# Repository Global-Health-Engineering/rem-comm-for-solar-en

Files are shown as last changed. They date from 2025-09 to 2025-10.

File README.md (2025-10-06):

<!-- badges: start -->


<!-- badges: end -->

<h1> Development of a Remote Communications Infrastructure for an Off-Grid Energy System: Hardware, Software, and Data </h1>

<b>Contributors</b>  
- Jerun Voeten <a href="https://orcid.org/0009-0009-9822-1285">
ORCID logo 0009-0009-9822-1285
</a> *author, developer, maintainer*  
- Rebecca Alcock <a href="https://orcid.org/0000-0002-6884-9583">
ORCID logo 0000-0002-6884-9583
</a> *supervisor*  
- Jakub Tkaczuk <a href="https://orcid.org/0000-0001-7997-9423">
ORCID logo 0000-0001-7997-9423
</a> *supervisor, maintainer*  
- Elizabeth Tilley <a href="https://orcid.org/0000-0002-2095-9724">
ORCID logo 0000-0002-2095-9724
</a> *supervisor*  

<br>
<p align="middle"> 

<br><br>
It complements the openly-accessible master’s thesis, available on the<br \>  
<a href="">ETH Research Collection</a>.
</p>

# Overview
Monitoring off-grid energy systems in remote locations with unreliable communications is challenging, yet it is essential in health facilities where continuous power supports patient care. Currently, there is no simple end-to-end solution that reliably captures all relevant variables and forwards them autonomously to a site with internet access for analysis and response.

This thesis develops such a system for an off-grid health clinic in Tezhumke, northern Colombia. The design combines existing low-power sensing and long-range radio techniques with practical extensions for constrained clinical sites. In particular, robustness measures and encoding optimizations were added to improve packet delivery over Long Range (LoRa) links, and the overall architecture was engineered to run autonomously from small photovoltaic panels and local power bank storage.

Custom sensor nodes record key measurements: medical refrigerator temperature and humidity, electrical parameters of the off-grid power system, and environmental data. Measurements are transmitted over LoRa and Long Range Wide-Area Network (LoRaWAN) to a gateway, visualized on an Internet of Things (IoT) platform (ThingsBoard), and automatically archived. Alarm rules notify remote researchers and on-site staff via platform alerts, email, SMS, and visual signals when thresholds are exceeded.

In a 7-day field trial, the system achieved a packet reception rate of 97.64% over a distance of 8.5km and demonstrated stable autonomous operation. These results confirm that the system is a mature prototype ready for extended field trials and potential deployment in real-world conditions. Future work should include extended seasonal testing, long-term studies of battery aging, and improvements to the weatherproofing of individual components.

Beyond the immediate use case in Tezhumke, the system may also be applicable to other similarly affected clinics or remote sites. With further refinement, it could support predictive maintenance strategies and contribute to improved reliability of off-grid power supplies, thereby strengthening healthcare delivery in underserved regions.

# Repository
As part of this Master thesis, all developed resources have been collected and systematically documented in this public GitHub repository. The repository serves as a comprehensive reference point for future research and practical applications. It includes:

- Source code for LoRa / LoRaWAN communication,
- ThingsBoard dashboard configuration and the main payload decryption script,
- Dedicated scripts for automated data export,
- PCB layouts and electronic circuit schematics,
- All custom-designed 3D models provided in STL format,
- A complete bill of materials for all hardware components.

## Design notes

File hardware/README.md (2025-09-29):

# `hardware`

This directory contains 3D designs, PCB layouts (KiCad), LoRa32u4II datasheet and a complete bill of materials for all hardware components.

# Power Bank Warning

Wires have been soldered to the + and – terminals of the power bank PCB (Solar Manager C). As a result, the manufacturer’s warranty is void, and I do not assume any responsibility in the event of issues, fire, or other incidents.
However, during the testing phase everything worked without any problems, and the functionality of the power bank did not appear to be affected.

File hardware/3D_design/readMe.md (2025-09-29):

# `hardware/3D_design`

This directory contains 3D designs for parts used in the project.

# Prior work

The Stevenson screen used in this work was adapted from the version originally created by [PYXIS. (2025, September 16). Stevenson Screen (Universal sensor mount) [STL file]. Bambu Studio](https://makerworld.com/de/models/851650-stevenson-screen-universal-sensor-mount?from=search#profileId-799909).

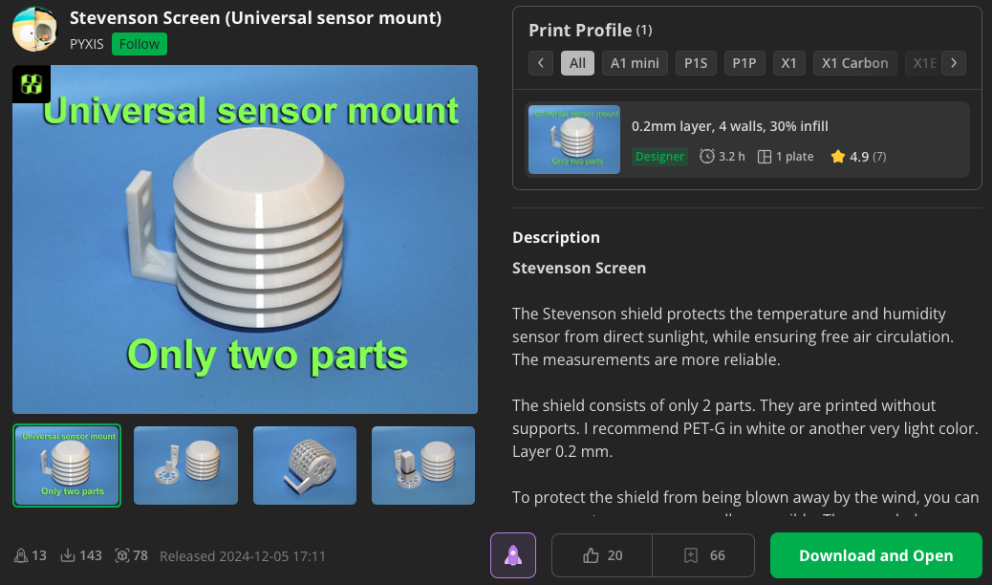
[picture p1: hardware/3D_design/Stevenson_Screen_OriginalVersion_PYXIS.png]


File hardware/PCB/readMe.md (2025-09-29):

# `hardware/PCB`

This directory contains PCB layouts and electronic circuit schematics created with KiCad for the:
- indoor node
- outdoor node
- repeater node

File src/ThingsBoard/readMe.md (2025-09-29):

# `src/ThingsBoard`

This folder contains the ThingsBoard configurations. The scripts can be uploaded in ThingsBoard on the respective pages.

Device profile settings:
    
- `dragino_device_profil.json`

Dashboard configuration:

- `indoor_measurements.json`
- `outdoor_measurements.json`

Rule chains:

- `root_rule_chain.json`
- `tezhumke_rule_chain.json`
- 
The `thingsboardMainScript.js` corresponds to the “decode tezhumke payload” script in the root rule chain and is responsible for decoding all payloads.

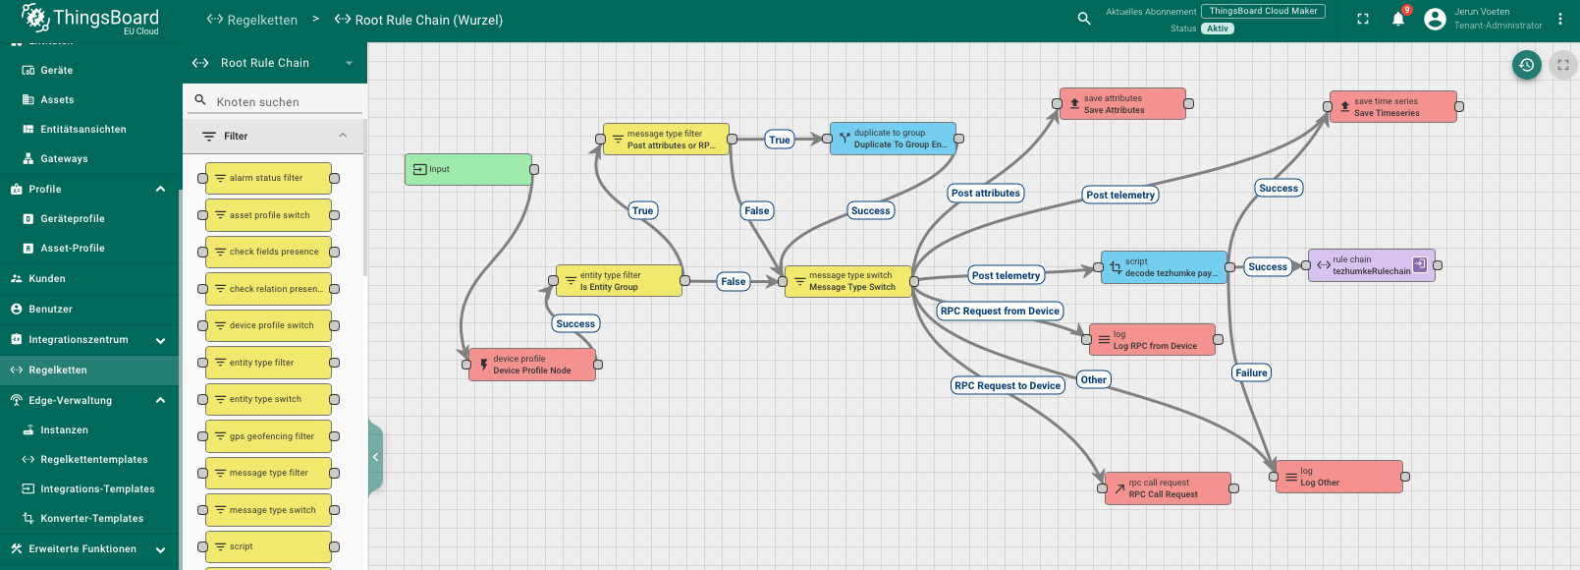
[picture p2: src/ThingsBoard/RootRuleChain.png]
Figure 1. Root rule chain

Figure 1. Root rule chain.

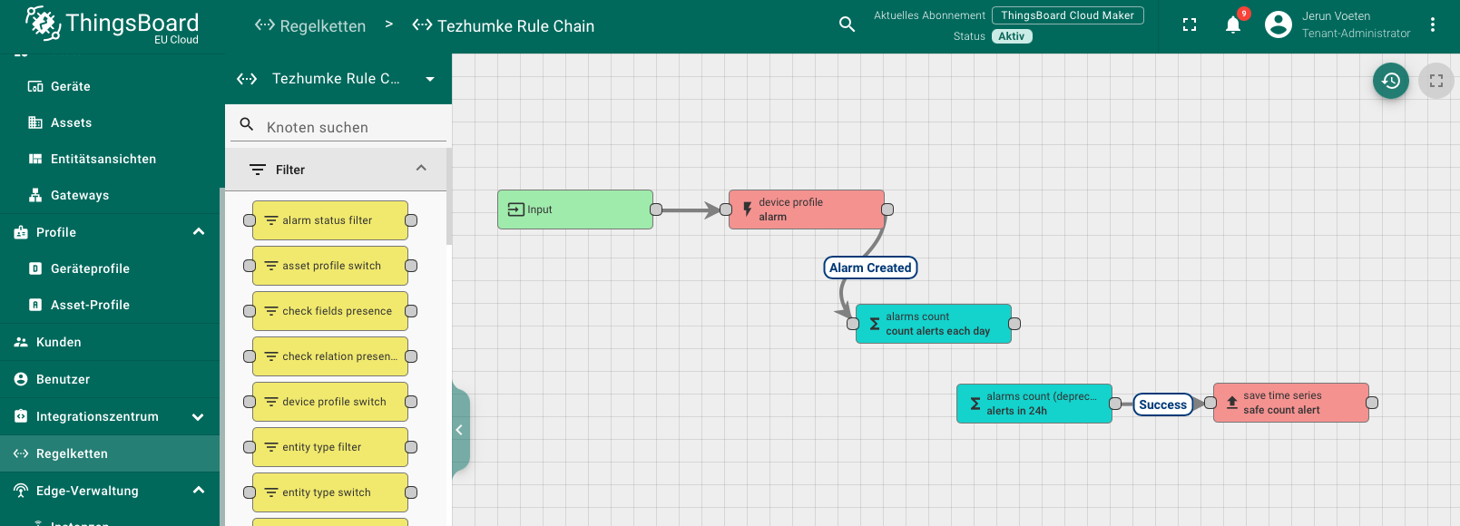
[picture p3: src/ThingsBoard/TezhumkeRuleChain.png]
Figure 2. Tezhumke rule chain

Figure 2. Tezhumke rule chain.

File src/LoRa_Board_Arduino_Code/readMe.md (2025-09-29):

# `src/LoRa_Board_Arduino_Code`

Here are the scripts running on the LoRa32u4II boards. The indoor and outdoor nodes collect data using sensors and transmit the information via LoRa to the repeater node. The repeater node, in turn, receives the data and forwards it via LoRaWAN to the gateway.

The `libraries` directory contains the required non-standard libraries.

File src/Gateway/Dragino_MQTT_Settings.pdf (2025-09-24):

## Dragino Settings: Send repeater data to ThingsBoard via MQTT (without TTN)

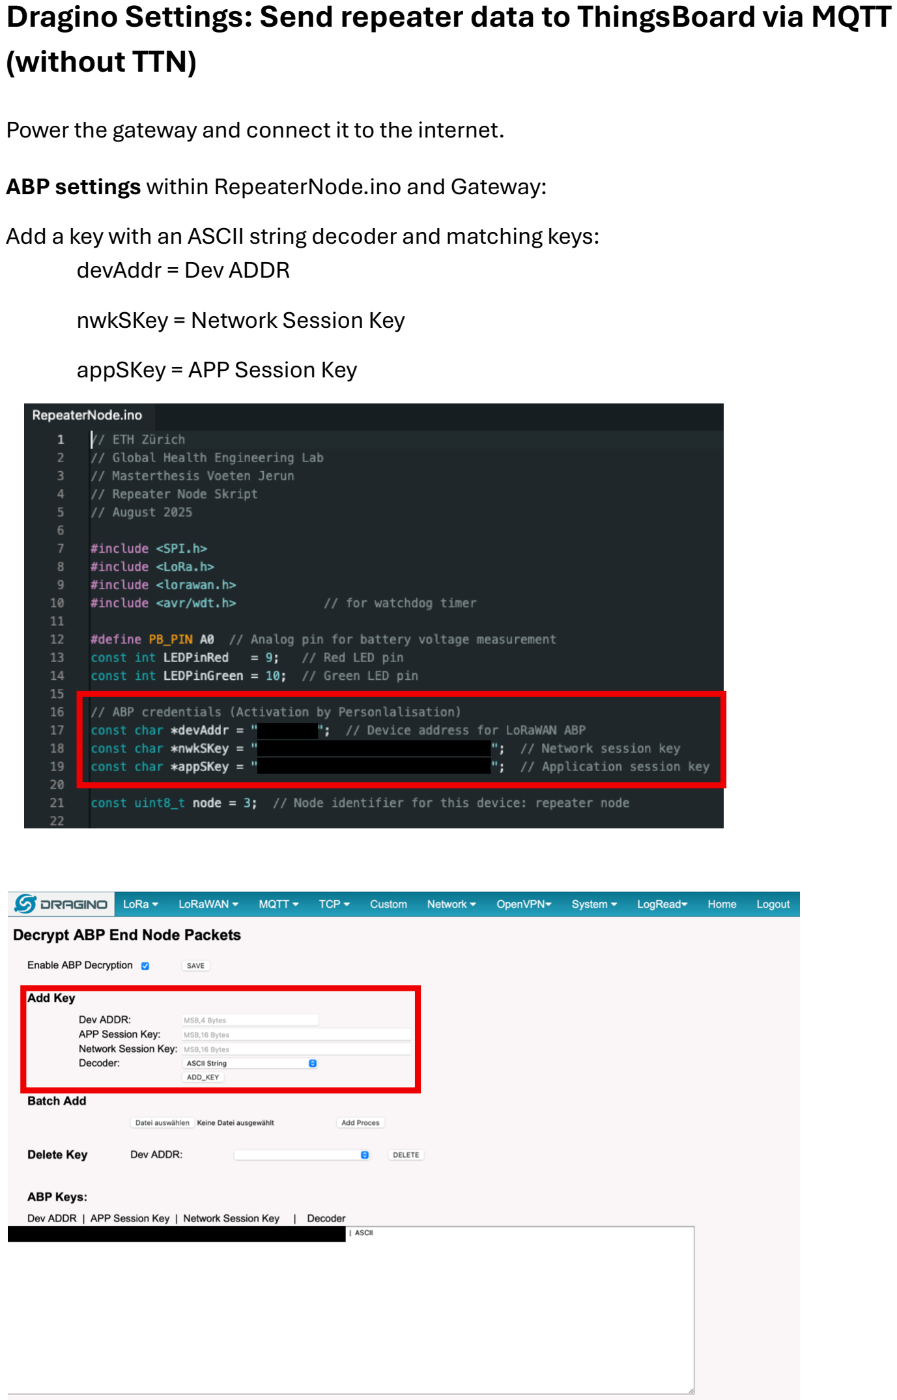
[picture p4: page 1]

Power the gateway and connect it to the internet.

ABP settings within RepeaterNode.ino and Gateway: Add a key with an ASCII string decoder and matching keys: devAddr = Dev ADDR
nwkSKey = Network Session Key
appSKey = APP Session Key

MQTT Client settings
Get the access token of your device in ThingsBoard and set required information within MQTT Client Configuration
Access token = User ID

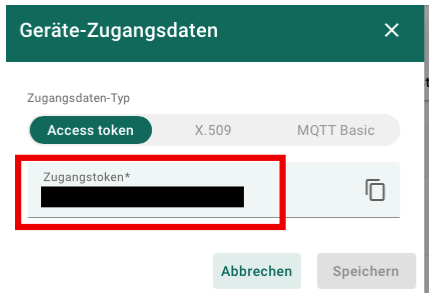
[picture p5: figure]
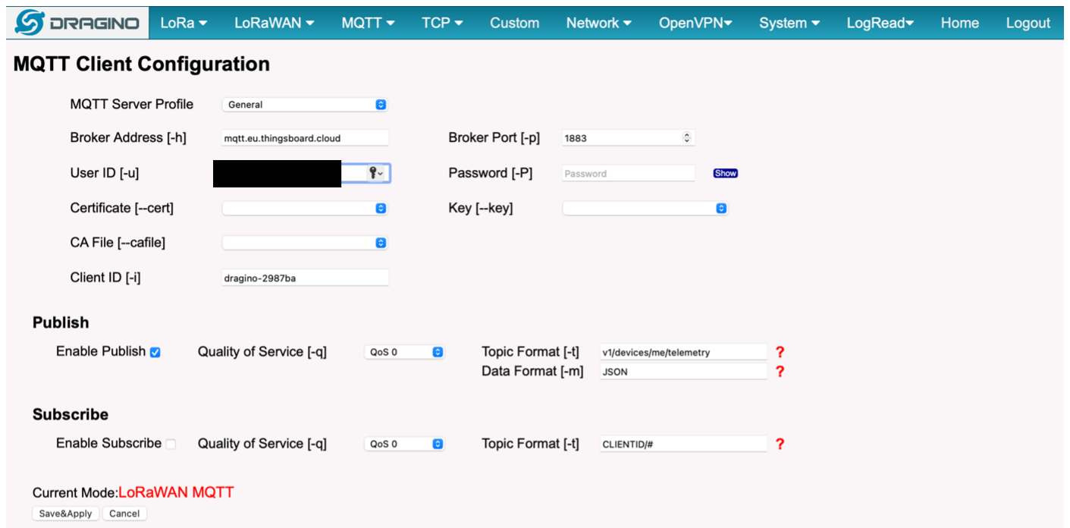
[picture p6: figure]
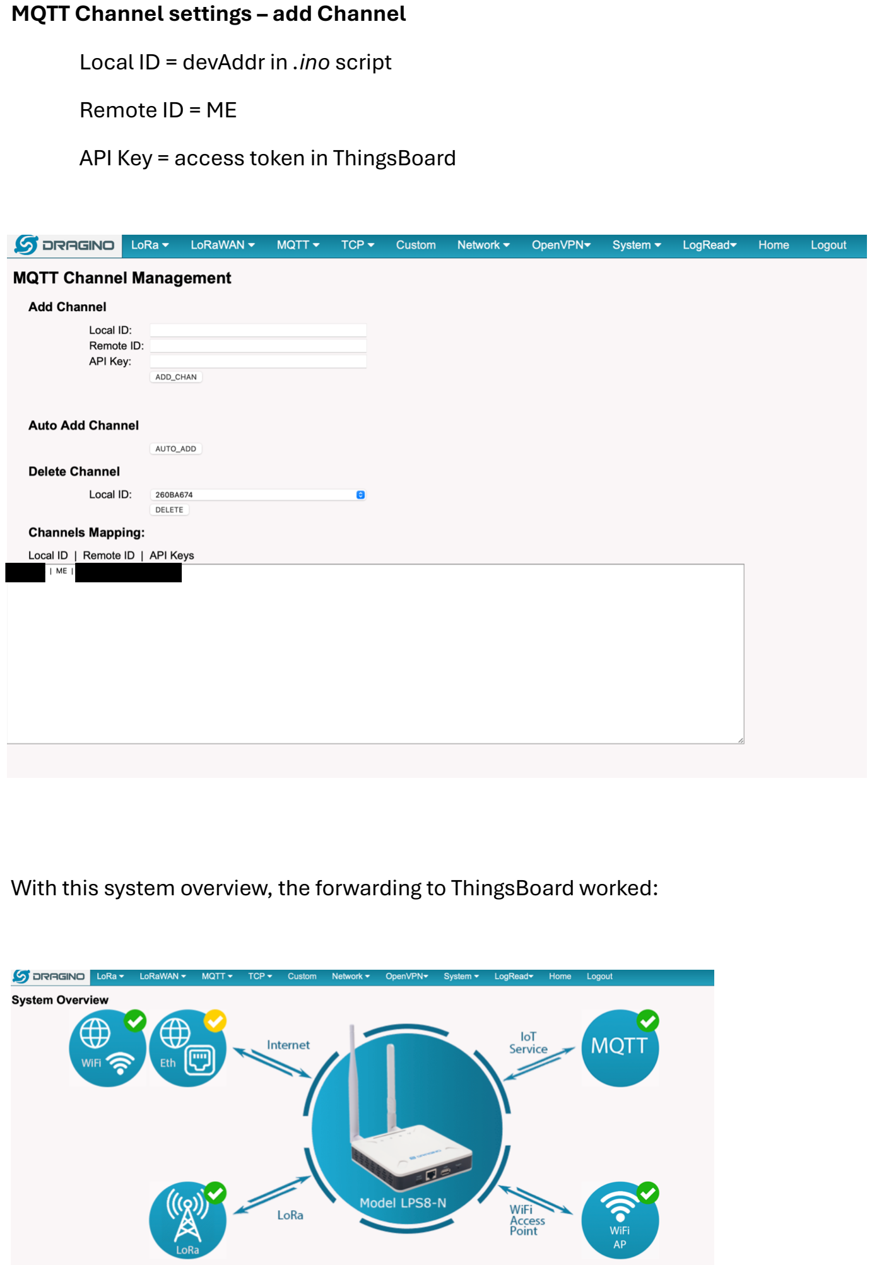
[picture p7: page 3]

MQTT Channel settings – add Channel Local ID = devAddr in .ino script Remote ID = ME
API Key = access token in ThingsBoard

With this system overview, the forwarding to ThingsBoard worked:

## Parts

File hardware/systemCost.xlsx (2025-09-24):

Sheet: All
Component | weblink | amount | unit price (CHF) | total price (CHF) |  | Explanation
microcontroller | https://www.amazon.com/-/de/gp/product/B07MVTSGBB/ref=ox_sc_act_title_1?smid=A28CGGHEZKZAJJ&psc=1 | 3 | 15 | 45
powerbank | https://www.bastelgarage.ch/solar-power-manager-c-for-6-24v-solar-panel?utm_source=chatgpt.com | 3 | 24 | 72
batteries for pb | https://www.bastelgarage.ch/li-ion-akku-3-7v-3200ma-ncr18650b-18650-mit-knopfpol | 9 | 9 | 81
pv | https://www.bastelgarage.ch/18v-0-61a-monocrystalline-solar-panel-10w?search=panel | 3 | 33 | 99
housing | https://www.bauhaus.ch/de/schalterdosen/feuchtraum-abzweigdose-t-box/p/23774755?gad_source=1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 | 3 | 10 | 30
indoor pcb | https://jlcpcb.com/de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 | 5 | 2 | 10 |  | minimum order 5pieces
outdoor pcb | https://jlcpcb.com/de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 | 5 | 2 | 10 |  | minimum order 5pieces
pcb components* |  | - | - | 16.6
cable gland M12 | https://www.bastelgarage.ch/kabelverschraubung-m12-ip68 | 10 | 1.5 | 15
cable gland M20 | https://www.bastelgarage.ch/kabelverschraubung-m20-ip68 | 3 | 1.9 | 5.7
led | https://www.distrelec.ch/de/led-signalleuchte-gruen-rot-gelb-8mm-2v-ip67-apem-q8f8gzzryg02e/p/30057427 | 3 | 10 | 30
short usb cable | https://www.conrad.ch/de/p/value-usb-2-0-kabel-usb-a-st-micro-usb-b-st-weiss-0-15-m-2557281.html | 3 | 2.5 | 7.5
windsensor | https://www.amazon.de/-/en/Haofy-Anemometer-Compatible-Wiring-Options/dp/B0D3QCJKPL | 1 | 65 | 65
temp & humidity sensor | https://www.bastelgarage.ch/dht22-temperature-and-humidity-sensor-plug-in | 2 | 13 | 26
light sensor | https://www.bastelgarage.ch/gravity-i2c-ambient-light-sensor-ip68 | 1 | 15 | 15
smart shunt | https://www.digitec.ch/de/s1/product/victron-energy-smartshunt-zubehoer-solarenergie-49025952?supplier=406802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 | 1 | 68 | 68
current sensor | https://www.conrad.ch/de/p/iduino-me067-stromsensor-1-st-1616236.html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 | 2 | 5 | 10
gateway | https://www.bastelgarage.ch/lps8n-indoor-multichannel-lorawan-gateway | 1 | 150 | 150
raspberry pi | https://www.brack.ch/raspberry-pi-entwicklerboard-raspberry-pi-4-model-b-1-gb-1024017?adgroup_id=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 | 1 | 45 | 45
SD Card | https://www.pi-shop.ch/raspberry-pi-a2-class-sd-card-32gb | 1 | 5.9 | 5.9
 |  |  |  | 806.7 | CHF
pcb components*
lever shifter | https://www.distrelec.ch/en/bss138-bi-directional-logic-level-converter-adafruit-757/p/30091221 | 1 | 5 | 5
Header socket 12pin | https://www.distrelec.ch/de/leiterplattenbuchse-buchse-3a-250v-anzahl-kontakte-12-wuerth-elektronik-61301211821/p/30024897 | 3 | 1 | 3
Header socket 16pin | https://www.distrelec.ch/de/leiterplattenbuchse-buchse-3a-250v-anzahl-kontakte-16-wuerth-elektronik-61301611821/p/30024908 | 3 | 1.2 | 3.6
scew terminal 3pin | https://www.distrelec.ch/de/printklemme-durchsteckmontage-16a-5mm-pole-packung-10-stueck-rs-pro-8970730/p/30426178 | 6 | 0.5 | 3
scew terminal 2pin | https://www.distrelec.ch/de/printklemme-durchsteckmontage-5mm-raster-rechter-winkel-verschraubung-pole-rnd-rnd-205-301-02p/p/30127865 | 7 | 0.2 | 1.4
jst ph2 | https://www.distrelec.ch/de/stiftleiste-einreihig-90-2p-rechts-abgewinkelt-stecker-positionen-jst-s2b-ph/p/14301956 | 3 | 0.2 | 0.6
resistor 220ohm | - | 6 | -
resistor 10kohm | - | 7 | -
resistor 22kohm | - | 3 | -
resistor 18kohm | - | 4 | -
resistor 100ohm | - | 1 | -
 |  |  |  | 16.6 | CHF
mini solar system
solar kit* (PV Panel, Solar power manager, AGM battery, Inverter) | https://swissbatt24.ch/solar/solar-sets/inselanlagen/1979/solaranlage-set-50w-mit-batterie-34ah-und-300w-wechselrichter-inkl.-nvs/usv-ladegeraet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 | 1 | 300 | 300 |  | This kit will allow us to replicate the solar system in Colombia on a smaller scale, collect data, and test the data transmission
cable lug , 6mm2, M6 | https://swissbatt24.ch/zubehoer/zubehoer-fuer-batterien/batteriekabel-kabelschuhe/batteriekabel-kabelschuhe/827/lapp-rohrkabelschuh-typ-a-m-se-cu-nach-din-136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 | 6 | 2 | 12
cable lug , 6mm2, M8 | https://swissbatt24.ch/zubehoer/zubehoer-fuer-batterien/batteriekabel-kabelschuhe/batteriekabel-kabelschuhe/827/lapp-rohrkabelschuh-typ-a-m-se-cu-nach-din-136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 | 4 | 2 | 8
Strip fuse 40A | https://swissbatt24.ch/wechselrichter/zubehoer/sicherungen/2820/votronic-streifensicherung-vpe-3-st.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 | 1 | 4 | 4
Strip fuse holder | https://swissbatt24.ch/wechselrichter/zubehoer/sicherungen/1953/votronic-2242-halter-fuer-streifensicherung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 | 1 | 8 | 8
(smart shunt)
 |  |  |  | 332 | CHF
components of solar kit*
inverter | https://swissbatt24.ch/wechselrichter/sinus-wechselrichter/mit-ladegeraet-nvs-usv/mit-ladegeraet-nvs-usv/1828/noqon-nsc312-300w/12v-sinus-wechselrichter-mit-l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 | -
PV panel | https://swissbatt24.ch/solar/solarmodule/alle-solarmodule/2161/voltima-genio-gsm50-40-solarmodul-50-watt-monokristallin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 | -
PV cable | https://swissbatt24.ch/photovoltaik/installation/kabel-stecker/2780/voltima-solar-kabel-set-6-mm2-mc4-einseitig-schwarz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 | -
Solar power manager | https://swissbatt24.ch/solar/laderegler/pwm-laderegler/1275/victron-energy-bluesolar-5a-pwm-solar-laderegler-12v/24v-batterie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 | -
AGM battery | https://swissbatt24.ch/traktionsbatterien/industriebatterien/multipower-mp-cyclic/694/multipower-mp34-12c-34ah-agm-batterie | -
Cable | https://swissbatt24.ch/zubehoer/zubehoer-fuer-batterien/batteriepflege-ueberwachung/batteriekabel-kabelschuhe/2781/voltima-anschlusskabel-set-einseitig-rohrka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 | -

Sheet: outdoor node
Component | weblink | amount | unit price (CHF) | total price (CHF) |  | Explanation
microcontroller | https://www.amazon.com/-/de/gp/product/B07MVTSGBB/ref=ox_sc_act_title_1?smid=A28CGGHEZKZAJJ&psc=1 | 1 | 15 | 15
windsensor | https://www.amazon.de/-/en/Haofy-Anemometer-Compatible-Wiring-Options/dp/B0D3QCJKPL | 1 | 65 | 65
temp & humidity sensor | https://www.bastelgarage.ch/dht22-temperature-and-humidity-sensor-plug-in | 1 | 13 | 13
light sensor | https://www.bastelgarage.ch/gravity-i2c-ambient-light-sensor-ip68 | 1 | 15 | 15
pv | https://www.bastelgarage.ch/18v-0-61a-monocrystalline-solar-panel-10w?search=panel | 1 | 33 | 33
housing | https://www.bauhaus.ch/de/schalterdosen/feuchtraum-abzweigdose-t-box/p/23774755?gad_source=1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 | 1 | 10 | 10
cable gland M12 | https://www.bastelgarage.ch/kabelverschraubung-m12-ip68 | 4 | 1.5 | 6
cable gland M20 | https://www.bastelgarage.ch/kabelverschraubung-m20-ip68 | 1 | 1.9 | 1.9
powerbank | https://www.bastelgarage.ch/solar-power-manager-c-for-6-24v-solar-panel?utm_source=chatgpt.com | 1 | 24 | 24
batteries for pb | https://www.bastelgarage.ch/li-ion-akku-3-7v-3200ma-ncr18650b-18650-mit-knopfpol | 3 | 9 | 27
led | https://www.distrelec.ch/de/led-signalleuchte-gruen-rot-gelb-8mm-2v-ip67-apem-q8f8gzzryg02e/p/30057427 | 1 | 10 | 10
short usb cable | https://www.conrad.ch/de/p/value-usb-2-0-kabel-usb-a-st-micro-usb-b-st-weiss-0-15-m-2557281.html | 1 | 2.5 | 2.5
pcb | https://jlcpcb.com/de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 | 1 | 2 | 10 |  | minimum order 5pieces
pcb components:
lever shifter | https://www.distrelec.ch/en/bss138-bi-directional-logic-level-converter-adafruit-757/p/30091221 | 1 | 5 | 5
Header socket 12pin | https://www.distrelec.ch/de/leiterplattenbuchse-buchse-3a-250v-anzahl-kontakte-12-wuerth-elektronik-61301211821/p/30024897 | 1 | 1 | 1
Header socket 16pin | https://www.distrelec.ch/de/leiterplattenbuchse-buchse-3a-250v-anzahl-kontakte-16-wuerth-elektronik-61301611821/p/30024908 | 1 | 1.2 | 1.2
scew terminal 3pin | https://www.distrelec.ch/de/printklemme-durchsteckmontage-16a-5mm-pole-packung-10-stueck-rs-pro-8970730/p/30426178 | 3 | 0.5 | 1.5
scew terminal 2pin | https://www.distrelec.ch/de/printklemme-durchsteckmontage-5mm-raster-rechter-winkel-verschraubung-pole-rnd-rnd-205-301-02p/p/30127865 | 2 | 0.2 | 0.4
jst ph2 | https://www.distrelec.ch/de/stiftleiste-einreihig-90-2p-rechts-abgewinkelt-stecker-positionen-jst-s2b-ph/p/14301956 | 1 | 0.2 | 0.2
resistor 220ohm | - | 2 | -
resistor 10kohm | - | 1 | -
resistor 22kohm | - | 1 | -
 |  |  |  | 241.7 | CHF

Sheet: indoor node
Component | weblink | amount | unit price (CHF) | total price (CHF) |  | Explanation
microcontroller | https://www.amazon.com/-/de/gp/product/B07MVTSGBB/ref=ox_sc_act_title_1?smid=A28CGGHEZKZAJJ&psc=1 | 1 | 15 | 15
smart shunt | https://www.digitec.ch/de/s1/product/victron-energy-smartshunt-zubehoer-solarenergie-49025952?supplier=406802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 | 1 | 68 | 68
temp & humidity sensor | https://www.bastelgarage.ch/dht22-temperature-and-humidity-sensor-plug-in | 1 | 13 | 13
current sensor | https://www.conrad.ch/de/p/iduino-me067-stromsensor-1-st-1616236.html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 | 2 | 5 | 10
pv | https://www.bastelgarage.ch/18v-0-61a-monocrystalline-solar-panel-10w?search=panel | 1 | 33 | 33
housing | https://www.bauhaus.ch/de/schalterdosen/feuchtraum-abzweigdose-t-box/p/23774755?gad_source=1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 | 1 | 10 | 10
cable gland M12 | https://www.bastelgarage.ch/kabelverschraubung-m12-ip68 | 5 | 1.5 | 7.5
cable gland M20 | https://www.bastelgarage.ch/kabelverschraubung-m20-ip68 | 1 | 1.9 | 1.9
powerbank | https://www.bastelgarage.ch/solar-power-manager-c-for-6-24v-solar-panel?utm_source=chatgpt.com | 1 | 24 | 24
batteries for pb | https://www.bastelgarage.ch/li-ion-akku-3-7v-3200ma-ncr18650b-18650-mit-knopfpol | 3 | 9 | 27
led | https://www.distrelec.ch/de/led-signalleuchte-gruen-rot-gelb-8mm-2v-ip67-apem-q8f8gzzryg02e/p/30057427 | 1 | 10 | 10
short usb cable | https://www.conrad.ch/de/p/value-usb-2-0-kabel-usb-a-st-micro-usb-b-st-weiss-0-15-m-2557281.html | 1 | 2.5 | 2.5
pcb | https://jlcpcb.com/de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 | 1 | 2 | 10 |  | minimum order 5pieces
pcb components:
Header socket 12pin | https://www.distrelec.ch/de/leiterplattenbuchse-buchse-3a-250v-anzahl-kontakte-12-wuerth-elektronik-61301211821/p/30024897 | 1 | 1 | 1
Header socket 16pin | https://www.distrelec.ch/de/leiterplattenbuchse-buchse-3a-250v-anzahl-kontakte-16-wuerth-elektronik-61301611821/p/30024908 | 1 | 1.2 | 1.2
scew terminal 3pin | https://www.distrelec.ch/de/printklemme-durchsteckmontage-16a-5mm-pole-packung-10-stueck-rs-pro-8970730/p/30426178 | 2 | 0.5 | 1
scew terminal 2pin | https://www.distrelec.ch/de/printklemme-durchsteckmontage-5mm-raster-rechter-winkel-verschraubung-pole-rnd-rnd-205-301-02p/p/30127865 | 5 | 0.2 | 1
jst ph2 | https://www.distrelec.ch/de/stiftleiste-einreihig-90-2p-rechts-abgewinkelt-stecker-positionen-jst-s2b-ph/p/14301956 | 1 | 0.2 | 0.2
resistor 220ohm | - | 2 | -
resistor 10kohm | - | 5 | -
resistor 22kohm | - | 1 | -
resistor 18kohm | - | 4 | -
resistor 100ohm | - | 1 | -
 |  |  |  | 236.3 | CHF
solar setup
solar kit (PV Panel, Solar power manager, AGM battery, Inverter) | https://swissbatt24.ch/solar/solar-sets/inselanlagen/1979/solaranlage-set-50w-mit-batterie-34ah-und-300w-wechselrichter-inkl.-nvs/usv-ladegeraet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 | 1 | 300 | 300
cable lug , 6mm2, M6 | https://swissbatt24.ch/zubehoer/zubehoer-fuer-batterien/batteriekabel-kabelschuhe/batteriekabel-kabelschuhe/827/lapp-rohrkabelschuh-typ-a-m-se-cu-nach-din-136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 | 6 | 2 | 12
cable lug , 6mm2, M8 | https://swissbatt24.ch/zubehoer/zubehoer-fuer-batterien/batteriekabel-kabelschuhe/batteriekabel-kabelschuhe/827/lapp-rohrkabelschuh-typ-a-m-se-cu-nach-din-136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 | 4 | 2 | 8
Strip fuse 40A | https://swissbatt24.ch/wechselrichter/zubehoer/sicherungen/2820/votronic-streifensicherung-vpe-3-st.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 | 1 | 4 | 4
Strip fuse holder | https://swissbatt24.ch/wechselrichter/zubehoer/sicherungen/1953/votronic-2242-halter-fuer-streifensicherung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 | 1 | 8 | 8
(smart shunt)
 |  |  |  | 332 | CHF

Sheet: repeater node
Component | weblink | amount | unit price (CHF) | total price (CHF) |  | Explanation
microcontroller | https://www.amazon.com/-/de/gp/product/B07MVTSGBB/ref=ox_sc_act_title_1?smid=A28CGGHEZKZAJJ&psc=1 | 1 | 15 | 15
pv | https://www.bastelgarage.ch/18v-0-61a-monocrystalline-solar-panel-10w?search=panel | 1 | 33 | 33
housing | https://www.bauhaus.ch/de/schalterdosen/feuchtraum-abzweigdose-t-box/p/23774755?gad_source=1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 | 1 | 10 | 10
cable gland M12 | https://www.bastelgarage.ch/kabelverschraubung-m12-ip68 | 1 | 1.5 | 1.5
cable gland M20 | https://www.bastelgarage.ch/kabelverschraubung-m20-ip68 | 1 | 1.9 | 1.9
powerbank | https://www.bastelgarage.ch/solar-power-manager-c-for-6-24v-solar-panel?utm_source=chatgpt.com | 1 | 24 | 24
batteries for pb | https://www.bastelgarage.ch/li-ion-akku-3-7v-3200ma-ncr18650b-18650-mit-knopfpol | 3 | 9 | 27
led | https://www.distrelec.ch/de/led-signalleuchte-gruen-rot-gelb-8mm-2v-ip67-apem-q8f8gzzryg02e/p/30057427 | 1 | 10 | 10
short usb cable | https://www.conrad.ch/de/p/value-usb-2-0-kabel-usb-a-st-micro-usb-b-st-weiss-0-15-m-2557281.html | 1 | 2.5 | 2.5
pcb | https://jlcpcb.com/de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 | 1 | 2 | 0 |  | use one of the indoor pcb's
pcb components:
Header socket 12pin | https://www.distrelec.ch/de/leiterplattenbuchse-buchse-3a-250v-anzahl-kontakte-12-wuerth-elektronik-61301211821/p/30024897 | 1 | 1 | 1
Header socket 16pin | https://www.distrelec.ch/de/leiterplattenbuchse-buchse-3a-250v-anzahl-kontakte-16-wuerth-elektronik-61301611821/p/30024908 | 1 | 1.2 | 1.2
scew terminal 3pin | https://www.distrelec.ch/de/printklemme-durchsteckmontage-16a-5mm-pole-packung-10-stueck-rs-pro-8970730/p/30426178 | 1 | 0.5 | 0.5
jst ph2 | https://www.distrelec.ch/de/stiftleiste-einreihig-90-2p-rechts-abgewinkelt-stecker-positionen-jst-s2b-ph/p/14301956 | 1 | 0.2 | 0.2
resistor 220ohm | - | 2 | -
resistor 10kohm | - | 1 | -
resistor 22kohm | - | 1 | -
 |  |  |  | 127.8 | CHF

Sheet: gateway node
Component | weblink | amount | unit price (CHF) | total price (CHF) |  | Explanation
gateway | https://www.bastelgarage.ch/lps8n-indoor-multichannel-lorawan-gateway | 1 | 150 | 150
raspberry pi | https://www.brack.ch/raspberry-pi-entwicklerboard-raspberry-pi-4-model-b-1-gb-1024017?adgroup_id=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 | 1 | 45 | 45
SD Card | https://www.pi-shop.ch/raspberry-pi-a2-class-sd-card-32gb | 1 | 5.9 | 5.9
 |  |  |  | 200.9 | CHF

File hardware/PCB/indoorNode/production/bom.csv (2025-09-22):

Designator | Footprint | Quantity | Value | LCSC Part #
J1 | TerminalBlock_MaiXu_MX126-5.0-03P_1x03_P5.00mm | 1 | LED
J2 | TerminalBlock_MaiXu_MX126-5.0-02P_1x02_P5.00mm | 1 | SmartShunt
J3 | JST_PH_B2B-PH-K_1x02_P2.00mm_Vertical | 1 | Battery +/-
J5 | TerminalBlock_MaiXu_MX126-5.0-08P_1x08_P5.00mm | 1 | ebikes
J6 | TerminalBlock_MaiXu_MX126-5.0-03P_1x03_P5.00mm | 1 | DHT22
R1 | R_Axial_DIN0207_L6.3mm_D2.5mm_P10.16mm_Horizontal | 1 | 22k
R10, R12, R14, R5, R8 | R_Axial_DIN0207_L6.3mm_D2.5mm_P10.16mm_Horizontal | 5 | 18k
R11, R13, R3, R6, R7, R9 | R_Axial_DIN0207_L6.3mm_D2.5mm_P10.16mm_Horizontal | 6 | 10k
R2, R4 | R_Axial_DIN0207_L6.3mm_D2.5mm_P10.16mm_Horizontal | 2 | 100
U1 | mod2_Adafruit_Feather_32u4_RFM_WithMountingHoles_1 | 1 | Feather 32u4 LoRa SMT

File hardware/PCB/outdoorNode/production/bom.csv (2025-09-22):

Designator | Footprint | Quantity | Value | LCSC Part #
J1 | TerminalBlock_MaiXu_MX126-5.0-03P_1x03_P5.00mm | 1 | LED
J2 | JST_PH_B2B-PH-K_1x02_P2.00mm_Vertical | 1 | Conn_01x02_Pin
J3 | PinHeader_2x06_P2.54mm_Vertical | 1 | Level Shift
J4 | TerminalBlock_MaiXu_MX126-5.0-03P_1x03_P5.00mm | 1 | Anemometer
J6 | TerminalBlock_MaiXu_MX126-5.0-03P_1x03_P5.00mm | 1 | DHT22
J7 | TerminalBlock_MaiXu_MX126-5.0-04P_1x04_P5.00mm | 1 | LightSensor
R1 | R_Axial_DIN0207_L6.3mm_D2.5mm_P10.16mm_Horizontal | 1 | 22k
R2, R4 | R_Axial_DIN0207_L6.3mm_D2.5mm_P10.16mm_Horizontal | 2 | 100
R3 | R_Axial_DIN0207_L6.3mm_D2.5mm_P10.16mm_Horizontal | 1 | 10k
U1 | mod2_Adafruit_Feather_32u4_RFM_WithMountingHoles_1 | 1 | Feather 32u4 LoRa SMT

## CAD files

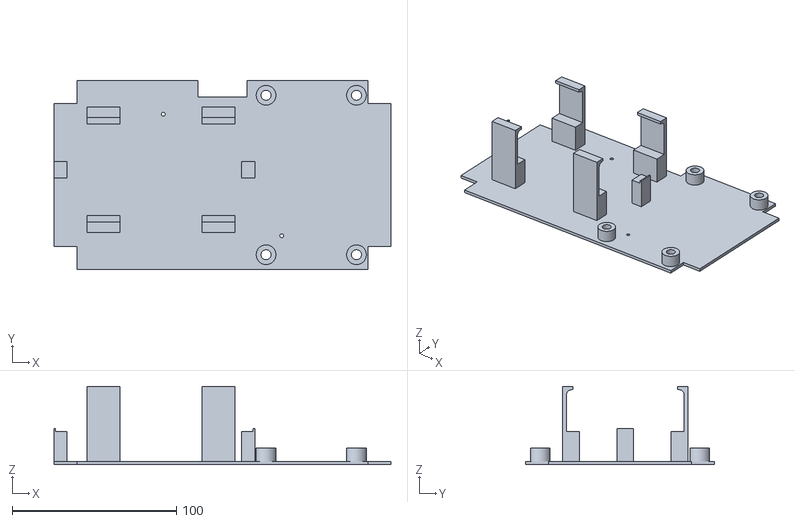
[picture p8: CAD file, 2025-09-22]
hardware/3D_design/Enclosure_Mounting_Plate.stl
205.0 x 115.0 x 47.5

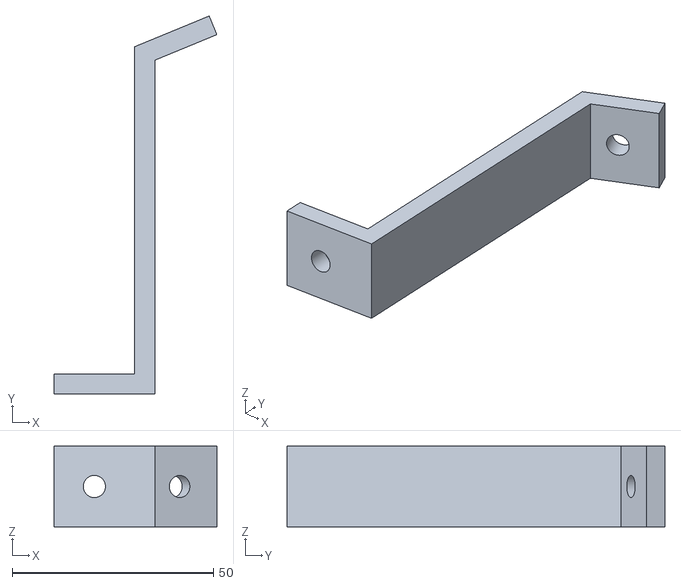
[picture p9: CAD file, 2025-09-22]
hardware/3D_design/PV_Fixation_Small.stl
40.4 x 93.8 x 20.0

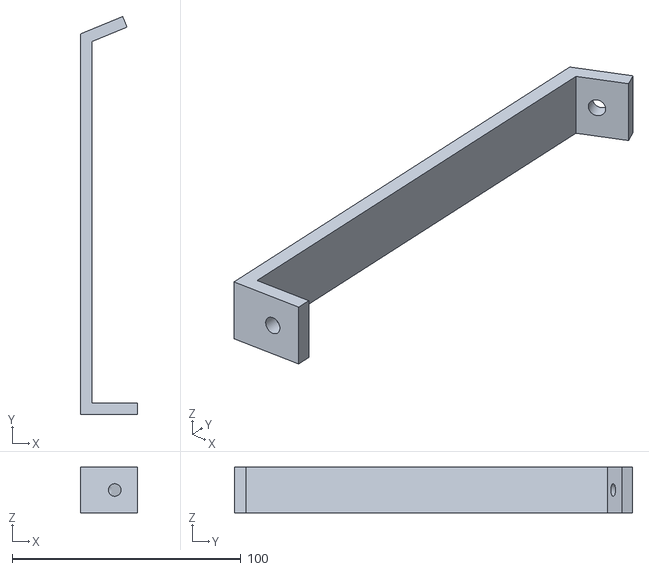
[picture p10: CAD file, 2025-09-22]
hardware/3D_design/PV_Fixation_Large.stl
25.0 x 173.8 x 20.0

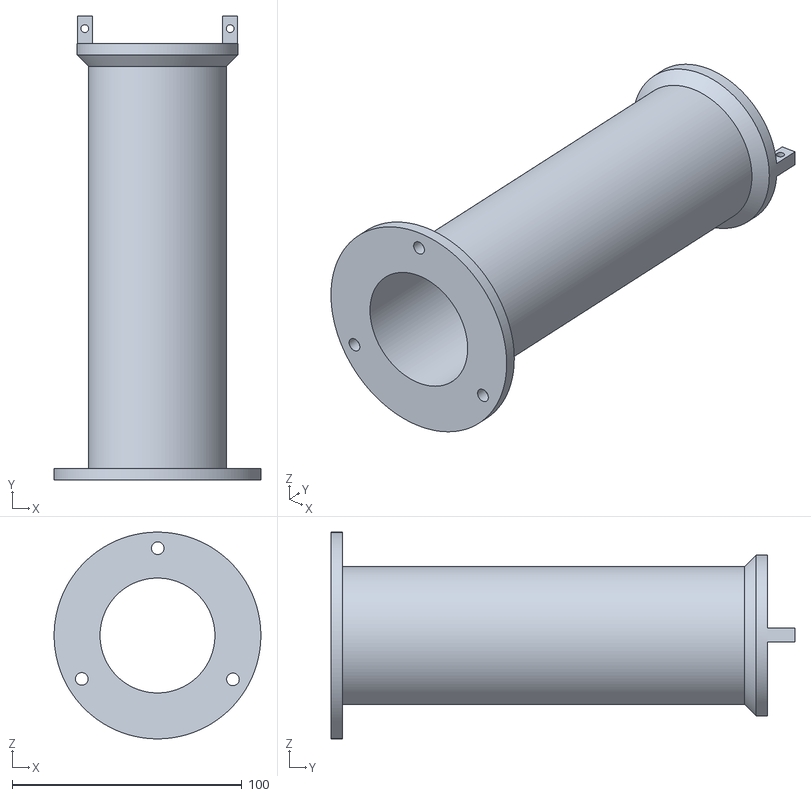
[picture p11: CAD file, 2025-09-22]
hardware/3D_design/Wind_Sensor_Mount.stl
90.0 x 202.0 x 90.0

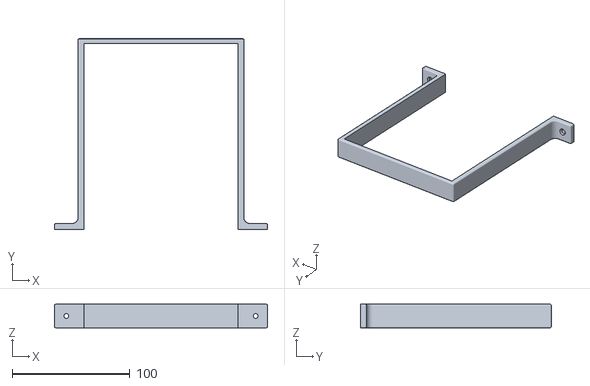
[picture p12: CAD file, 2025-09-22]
hardware/3D_design/Battery_Fixation.stl
181.0 x 162.0 x 20.0

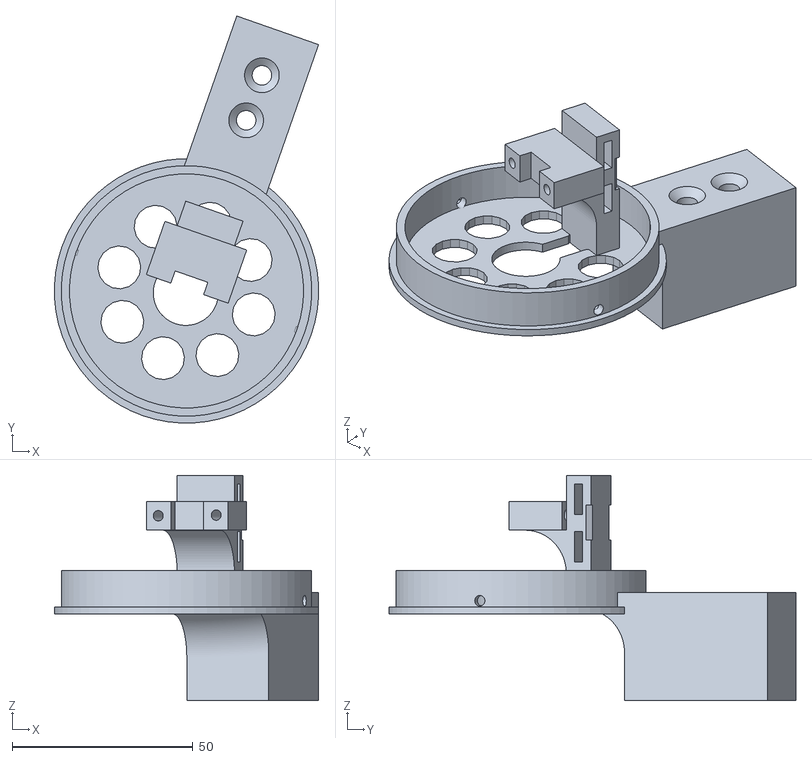
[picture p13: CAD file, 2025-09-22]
hardware/3D_design/Adapted_Stevenson_Screen_mount_Original_By_PYXIS.stl
73.1 x 112.7 x 62.4

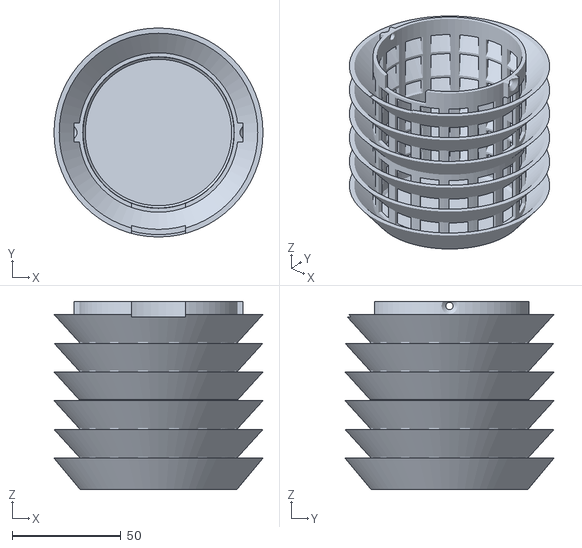
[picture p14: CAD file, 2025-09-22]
hardware/3D_design/Adapted_Stevenson_Screen_Original_By_PYXIS.stl
96.0 x 96.0 x 86.4

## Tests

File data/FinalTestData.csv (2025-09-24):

Timestamp | payload | node | InNodeBatSOC | InNodeBatStatus | fridgeTemp | fridgeHum | InDHTStatus | mainBatSOC | mainBatVoltage | mainBatCurrent | consumed_mAh | chargeCycles | SmartShuntStatus | eBikeState1 | eBikeState2 | eBikeState3 | eBikeState4 | OutNodeBatSOC | outNodeBatStatus | outTemp | outHum | OutDHTStatus | illuminance | OutLightStatus | windspeed | OutWindStatus | repNodeBatSOC | repNodeBatStatus
2025-08-10 18:00:37 | 0100005c019a6003e80089000400 00000000060078 | 1 | 96 | OK | 9.2 | 41 | OK | 100 | 13.7 | 0.4 | 0 | 0 | OK | Discharging | Charging | Not Docked | Not Docked
2025-08-10 18:00:40 | 0200011701cdafad00035f00f45b | 2 |  |  |  |  |  |  |  |  |  |  |  |  |  |  |  | 95 | OK | 27.9 | 46.1 | OK | 44973 | OK | 0.3 | OK | 91 | OK
2025-08-10 18:03:00 | c3 | 3 |  | OK |  |  |  |  |  |  |  |  |  |  |  |  |  |  | Error |  |  |  |  |  |  |  | 93 | OK
2025-08-10 18:03:03 | 0100005a018a6003e80089000300 00000000060082 | 1 | 96 | OK | 9 | 39.4 | OK | 100 | 13.7 | 0.3 | 0 | 0 | OK | Discharging | Charging | Not Docked | Not Docked
2025-08-10 18:04:41 | 01000059017a6003e80088000400 000000000600b1 | 1 | 96 | OK | 8.9 | 37.8 | OK | 100 | 13.6 | 0.4 | 0 | 0 | OK | Discharging | Charging | Not Docked | Not Docked
2025-08-10 18:04:44 | 0200011501d8ab9d00005c007e5d | 2 |  |  |  |  |  |  |  |  |  |  |  |  |  |  |  | 92 | OK | 27.7 | 47.2 | OK | 43933 | OK | 0 | OK | 93 | OK
2025-08-10 18:06:41 | 0100005701696003e80088000300 000000000600b3 | 1 | 96 | OK | 8.7 | 36.1 | OK | 100 | 13.6 | 0.3 | 0 | 0 | OK | Discharging | Charging | Not Docked | Not Docked
2025-08-10 18:06:45 | 0200011701d3a86a00015f00c95d | 2 |  |  |  |  |  |  |  |  |  |  |  |  |  |  |  | 95 | OK | 27.9 | 46.7 | OK | 43114 | OK | 0.1 | OK | 93 | OK
2025-08-10 18:08:38 | 0100005601616003e80089000400 000000000600e6 | 1 | 96 | OK | 8.6 | 35.3 | OK | 100 | 13.7 | 0.4 | 0 | 0 | OK | Discharging | Charging | Not Docked | Not Docked
2025-08-10 18:08:41 | 0200011b01c9a56400005f00055d | 2 |  |  |  |  |  |  |  |  |  |  |  |  |  |  |  | 95 | OK | 28.3 | 45.7 | OK | 42340 | OK | 0 | OK | 93 | OK
2025-08-10 18:10:40 | 0100005601676003e80088000300 000000000600d3 | 1 | 96 | OK | 8.6 | 35.9 | OK | 100 | 13.6 | 0.3 | 0 | 0 | OK | Discharging | Charging | Not Docked | Not Docked
2025-08-10 18:10:43 | 0200011d01b9a23400006000005d | 2 |  |  |  |  |  |  |  |  |  |  |  |  |  |  |  | 96 | OK | 28.5 | 44.1 | OK | 41524 | OK | 0 | OK | 93 | OK
2025-08-10 18:12:38 | 01000056016c6003e80088000300 0000000006002e | 1 | 96 | OK | 8.6 | 36.4 | OK | 100 | 13.6 | 0.3 | 0 | 0 | OK | Discharging | Charging | Not Docked | Not Docked
2025-08-10 18:12:41 | 0200011a01a29f8300005f00965d | 2 |  |  |  |  |  |  |  |  |  |  |  |  |  |  |  | 95 | OK | 28.2 | 41.8 | OK | 40835 | OK | 0 | OK | 93 | OK
2025-08-10 18:14:38 | 0100005701745e03e80089000300 000000000600fd | 1 | 94 | OK | 8.7 | 37.2 | OK | 100 | 13.7 | 0.3 | 0 | 0 | OK | Discharging | Charging | Not Docked | Not Docked
2025-08-10 18:14:41 | 0200011501ae9da800065f00ae5b | 2 |  |  |  |  |  |  |  |  |  |  |  |  |  |  |  | 95 | OK | 27.7 | 43 | OK | 40360 | OK | 0.6 | OK | 91 | OK
2025-08-10 18:16:39 | 01000058017f6003e80088565330 060000000600fc
2025-08-10 18:16:42 | 0200011501c79bba00005d00475c | 2 |  |  |  |  |  |  |  |  |  |  |  |  |  |  |  | 93 | OK | 27.7 | 45.5 | OK | 39866 | OK | 0 | OK | 92 | OK
2025-08-10 18:18:40 | 01000058018d6003e80089000300 00000000060077 | 1 | 96 | OK | 8.8 | 39.7 | OK | 100 | 13.7 | 0.3 | 0 | 0 | OK | Discharging | Charging | Not Docked | Not Docked
2025-08-10 18:18:43 | 0200011601b1995900055f00b15d | 2 |  |  |  |  |  |  |  |  |  |  |  |  |  |  |  | 95 | OK | 27.8 | 43.3 | OK | 39257 | OK | 0.5 | OK | 93 | OK
2025-08-10 18:20:43 | 01000059019e5f03e80088000300 00000000060075 | 1 | 95 | OK | 8.9 | 41.4 | OK | 100 | 13.6 | 0.3 | 0 | 0 | OK | Discharging | Charging | Not Docked | Not Docked
2025-08-10 18:20:46 | 0200011801b0968700086000df5c | 2 |  |  |  |  |  |  |  |  |  |  |  |  |  |  |  | 96 | OK | 28 | 43.2 | OK | 38535 | OK | 0.8 | OK | 92 | OK
2025-08-10 18:22:40 | 0100005a01af5f03e80088000300 000000000600c5 | 1 | 95 | OK | 9 | 43.1 | OK | 100 | 13.6 | 0.3 | 0 | 0 | OK | Discharging | Charging | Not Docked | Not Docked
2025-08-10 18:22:44 | 0200011201c9931c00015f005b5d | 2 |  |  |  |  |  |  |  |  |  |  |  |  |  |  |  | 95 | OK | 27.4 | 45.7 | OK | 37660 | OK | 0.1 | OK | 93 | OK
2025-08-10 18:24:41 | 0100005b01bf5f03e80088000300 00000000060022 | 1 | 95 | OK | 9.1 | 44.7 | OK | 100 | 13.6 | 0.3 | 0 | 0 | OK | Discharging | Charging | Not Docked | Not Docked
2025-08-10 18:24:44 | 0200011601d3915c00005c00f05c | 2 |  |  |  |  |  |  |  |  |  |  |  |  |  |  |  | 92 | OK | 27.8 | 46.7 | OK | 37212 | OK | 0 | OK | 92 | OK
2025-08-10 18:26:40 | 0100005c01d05f03e80088000300 000000000600a2 | 1 | 95 | OK | 9.2 | 46.4 | OK | 100 | 13.6 | 0.3 | 0 | 0 | OK | Discharging | Charging | Not Docked | Not Docked
2025-08-10 18:26:43 | 0200011501ae8f1a000c5f003d5d | 2 |  |  |  |  |  |  |  |  |  |  |  |  |  |  |  | 95 | OK | 27.7 | 43 | OK | 36634 | OK | 1.2 | OK | 93 | OK
2025-08-10 18:28:43 | 0100005d01df5f03e80088000300 00000000060042 | 1 | 95 | OK | 9.3 | 47.9 | OK | 100 | 13.6 | 0.3 | 0 | 0 | OK | Discharging | Charging | Not Docked | Not Docked
2025-08-10 18:28:46 | 0200011301ef8c4300056000b05d | 2 |  |  |  |  |  |  |  |  |  |  |  |  |  |  |  | 96 | OK | 27.5 | 49.5 | OK | 35907 | OK | 0.5 | OK | 93 | OK
2025-08-10 18:30:41 | 0100005e01ef5f03e80088000300 00000000060072 | 1 | 95 | OK | 9.4 | 49.5 | OK | 100 | 13.6 | 0.3 | 0 | 0 | OK | Discharging | Charging | Not Docked | Not Docked
2025-08-10 18:30:44 | 0200011601de8a2000065f00a35d | 2 |  |  |  |  |  |  |  |  |  |  |  |  |  |  |  | 95 | OK | 27.8 | 47.8 | OK | 35360 | OK | 0.6 | OK | 93 | OK
2025-08-10 18:32:44 | 0100005f01fb5e03e80088000300 0000000006008b | 1 | 94 | OK | 9.5 | 50.7 | OK | 100 | 13.6 | 0.3 | 0 | 0 | OK | Discharging | Charging | Not Docked | Not Docked
2025-08-10 18:32:47 | 0200010f01c387c600015f00555d | 2 |  |  |  |  |  |  |  |  |  |  |  |  |  |  |  | 95 | OK | 27.1 | 45.1 | OK | 34758 | OK | 0.1 | OK | 93 | OK
2025-08-10 18:34:44 | 0100006002055d03e80089000300 0000000006005c | 1 | 93 | OK | 9.6 | 51.7 | OK | 100 | 13.7 | 0.3 | 0 | 0 | OK | Discharging | Charging | Not Docked | Not Docked
2025-08-10 18:34:47 | 0200010e01b9862e00055f00e45d | 2 |  |  |  |  |  |  |  |  |  |  |  |  |  |  |  | 95 | OK | 27 | 44.1 | OK | 34350 | OK | 0.5 | OK | 93 | OK
2025-08-10 18:36:43 | 01000061020e5f03e80089000300 000000000600d6 | 1 | 95 | OK | 9.7 | 52.6 | OK | 100 | 13.7 | 0.3 | 0 | 0 | OK | Discharging | Charging | Not Docked | Not Docked
2025-08-10 18:36:46 | 0200011001cb83c900005e00c85b | 2 |  |  |  |  |  |  |  |  |  |  |  |  |  |  |  | 94 | OK | 27.2 | 45.9 | OK | 33737 | OK | 0 | OK | 91 | OK
2025-08-10 18:38:43 | 0100006202185d03e80089000300 0000000006001c | 1 | 93 | OK | 9.8 | 53.6 | OK | 100 | 13.7 | 0.3 | 0 | 0 | OK | Discharging | Charging | Not Docked | Not Docked
2025-08-10 18:38:46 | 0200011301d381c100005d00325d | 2 |  |  |  |  |  |  |  |  |  |  |  |  |  |  |  | 93 | OK | 27.5 | 46.7 | OK | 33217 | OK | 0 | OK | 93 | OK
2025-08-10 18:40:44 | 0100006302205f03e80089000300 0000000006004e | 1 | 95 | OK | 9.9 | 54.4 | OK | 100 | 13.7 | 0.3 | 0 | 0 | OK | Discharging | Charging | Not Docked | Not Docked
2025-08-10 18:40:47 | 0200011101d07ee500005c00515d | 2 |  |  |  |  |  |  |  |  |  |  |  |  |  |  |  | 92 | OK | 27.3 | 46.4 | OK | 32485 | OK | 0 | OK | 93 | OK
2025-08-10 18:42:44 | 0100006402295f03e80089000300 00000000060067 | 1 | 95 | OK | 10 | 55.3 | OK | 100 | 13.7 | 0.3 | 0 | 0 | OK | Discharging | Charging | Not Docked | Not Docked
2025-08-10 18:42:47 | 0200011201e9676800005e00075d | 2 |  |  |  |  |  |  |  |  |  |  |  |  |  |  |  | 94 | OK | 27.4 | 48.9 | OK | 26472 | OK | 0 | OK | 93 | OK
2025-08-10 18:44:43 | 0100006502325f03e80088000300 000000000600b3 | 1 | 95 | OK | 10.1 | 56.2 | OK | 100 | 13.6 | 0.3 | 0 | 0 | OK | Discharging | Charging | Not Docked | Not Docked
2025-08-10 18:44:46 | 0200011201da33b3000c5e00335d | 2 |  |  |  |  |  |  |  |  |  |  |  |  |  |  |  | 94 | OK | 27.4 | 47.4 | OK | 13235 | OK | 1.2 | OK | 93 | OK
2025-08-10 18:46:45 | 01000065023b5f03e80088000300 00000000060057 | 1 | 95 | OK | 10.1 | 57.1 | OK | 100 | 13.6 | 0.3 | 0 | 0 | OK | Discharging | Charging | Not Docked | Not Docked
2025-08-10 18:46:48 | 0200010e01e5251d00005f00275c | 2 |  |  |  |  |  |  |  |  |  |  |  |  |  |  |  | 95 | OK | 27 | 48.5 | OK | 9501 | OK | 0 | OK | 92 | OK
2025-08-10 18:48:44 | 0100006602445f03e80088000300 000000000600a3 | 1 | 95 | OK | 10.2 | 58 | OK | 100 | 13.6 | 0.3 | 0 | 0 | OK | Discharging | Charging | Not Docked | Not Docked
2025-08-10 18:48:47 | 0200010801ed211900005f00e65d | 2 |  |  |  |  |  |  |  |  |  |  |  |  |  |  |  | 95 | OK | 26.4 | 49.3 | OK | 8473 | OK | 0 | OK | 93 | OK
2025-08-10 18:50:44 | 01000067024e6003e80088000300 00000000060043 | 1 | 96 | OK | 10.3 | 59 | OK | 100 | 13.6 | 0.3 | 0 | 0 | OK | Discharging | Charging | Not Docked | Not Docked
2025-08-10 18:50:47 | a0a0cf0489c402c77d890eb6ce0a
2025-08-10 18:52:47 | 0100006802555f03e80089000300 000000000600a6 | 1 | 95 | OK | 10.4 | 59.7 | OK | 100 | 13.7 | 0.3 | 0 | 0 | OK | Discharging | Charging | Not Docked | Not Docked
2025-08-10 18:52:50 | 0200010401ec27f100095e00385c | 2 |  |  |  |  |  |  |  |  |  |  |  |  |  |  |  | 94 | OK | 26 | 49.2 | OK | 10225 | OK | 0.9 | OK | 92 | OK
2025-08-10 18:54:45 | 01000069025d5f03e80088000300 00000000060023 | 1 | 95 | OK | 10.5 | 60.5 | OK | 100 | 13.6 | 0.3 | 0 | 0 | OK | Discharging | Charging | Not Docked | Not Docked
2025-08-10 18:54:48 | 0200010101f62a2e00055d00db5c | 2 |  |  |  |  |  |  |  |  |  |  |  |  |  |  |  | 93 | OK | 25.7 | 50.2 | OK | 10798 | OK | 0.5 | OK | 92 | OK
2025-08-10 18:56:44 | 0100006a02635f03e80088000300 0000000006005c | 1 | 95 | OK | 10.6 | 61.1 | OK | 100 | 13.6 | 0.3 | 0 | 0 | OK | Discharging | Charging | Not Docked | Not Docked
2025-08-10 18:56:47 | 0200010101ff20c100005b00f25b | 2 |  |  |  |  |  |  |  |  |  |  |  |  |  |  |  | 91 | OK | 25.7 | 51.1 | OK | 8385 | OK | 0 | OK | 91 | OK
2025-08-10 18:58:49 | 0100006b02695f03e80086000200 000000000600fd | 1 | 95 | OK | 10.7 | 61.7 | OK | 100 | 13.4 | 0.2 | 0 | 0 | OK | Discharging | Charging | Not Docked | Not Docked
2025-08-10 18:58:52 | 020000fc01fb1c4700006000fa5b | 2 |  |  |  |  |  |  |  |  |  |  |  |  |  |  |  | 96 | OK | 25.2 | 50.7 | OK | 7239 | OK | 0 | OK | 91 | OK
2025-08-10 19:00:47 | 0100006a02705d03e80085000200 000000000600ed | 1 | 93 | OK | 10.6 | 62.4 | OK | 100 | 13.3 | 0.2 | 0 | 0 | OK | Discharging | Charging | Not Docked | Not Docked
2025-08-10 19:00:51 | 020000fb020a1bb500005e00405c | 2 |  |  |  |  |  |  |  |  |  |  |  |  |  |  |  | 94 | OK | 25.1 | 52.2 | OK | 7093 | OK | 0 | OK | 92 | OK
2025-08-10 19:02:48 | 01000069027e5f03e80085000200 0000000006008b | 1 | 95 | OK | 10.5 | 63.8 | OK | 100 | 13.3 | 0.2 | 0 | 0 | OK | Discharging | Charging | Not Docked | Not Docked
2025-08-10 19:02:51 | 020000fb01fe1b6600045f007f5d | 2 |  |  |  |  |  |  |  |  |  |  |  |  |  |  |  | 95 | OK | 25.1 | 51 | OK | 7014 | OK | 0.4 | OK | 93 | OK
2025-08-10 19:04:47 | 01000068027a5f03e80085000200 00000000060096 | 1 | 95 | OK | 10.4 | 63.4 | OK | 100 | 13.3 | 0.2 | 0 | 0 | OK | Discharging | Charging | Not Docked | Not Docked
2025-08-10 19:04:50 | 020000f802141bfb000c5c00505c | 2 |  |  |  |  |  |  |  |  |  |  |  |  |  |  |  | 92 | OK | 24.8 | 53.2 | OK | 7163 | OK | 1.2 | OK | 92 | OK
2025-08-10 19:06:47 | 0100006702635f03e80085000200 00000000060016 | 1 | 95 | OK | 10.3 | 61.1 | OK | 100 | 13.3 | 0.2 | 0 | 0 | OK | Discharging | Charging | Not Docked | Not Docked
2025-08-10 19:06:50 | 020000f801fd213400095f00e95c | 2 |  |  |  |  |  |  |  |  |  |  |  |  |  |  |  | 95 | OK | 24.8 | 50.9 | OK | 8500 | OK | 0.9 | OK | 92 | OK
2025-08-10 19:08:47 | 0100006502405f03e80085000200 00000000060058 | 1 | 95 | OK | 10.1 | 57.6 | OK | 100 | 13.3 | 0.2 | 0 | 0 | OK | Discharging | Charging | Not Docked | Not Docked
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

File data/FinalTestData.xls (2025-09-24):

Timestamp | node | InNodeBatSOC | InNodeBatStatus | fridgeTemp | fridgeHum | InDHTStatus | mainBatSOC | mainBatVoltage | mainBatCurrent | consumed_mAh | chargeCycles | SmartShuntStatus | eBikeState1 | eBikeState2 | eBikeState3 | eBikeState4 | OutNodeBatSOC | outNodeBatStatus | outTemp | outHum | OutDHTStatus | illuminance | OutLightStatus | windspeed | OutWindStatus | repNodeBatSOC | repNodeBatStatus
2025-08-10 18:00 | 1 | 96 | OK | 9.2 | 41 | OK | 100 | 13.7 | 0.4 |  |  | OK | Discharging | Charging | Not Docked | Not Docked
2025-08-10 18:00 | 2 |  |  |  |  |  |  |  |  |  |  |  |  |  |  |  | 95 | OK | 27.9 | 46.1 | OK | 44973 | OK | 0.3 | OK | 91 | OK
2025-08-10 18:03 | 3 |  | OK |  |  |  |  |  |  |  |  |  |  |  |  |  |  | Error |  |  |  |  |  |  |  | 93 | OK
2025-08-10 18:03 | 1 | 96 | OK | 9 | 39.4 | OK | 100 | 13.7 | 0.3 |  |  | OK | Discharging | Charging | Not Docked | Not Docked
2025-08-10 18:04 | 1 | 96 | OK | 8.9 | 37.8 | OK | 100 | 13.6 | 0.4 |  |  | OK | Discharging | Charging | Not Docked | Not Docked
2025-08-10 18:04 | 2 |  |  |  |  |  |  |  |  |  |  |  |  |  |  |  | 92 | OK | 27.7 | 47.2 | OK | 43933 | OK |  | OK | 93 | OK
2025-08-10 18:06 | 1 | 96 | OK | 8.7 | 36.1 | OK | 100 | 13.6 | 0.3 |  |  | OK | Discharging | Charging | Not Docked | Not Docked
2025-08-10 18:06 | 2 |  |  |  |  |  |  |  |  |  |  |  |  |  |  |  | 95 | OK | 27.9 | 46.7 | OK | 43114 | OK | 0.1 | OK | 93 | OK
2025-08-10 18:08 | 1 | 96 | OK | 8.6 | 35.3 | OK | 100 | 13.7 | 0.4 |  |  | OK | Discharging | Charging | Not Docked | Not Docked
2025-08-10 18:08 | 2 |  |  |  |  |  |  |  |  |  |  |  |  |  |  |  | 95 | OK | 28.3 | 45.7 | OK | 42340 | OK |  | OK | 93 | OK
2025-08-10 18:10 | 1 | 96 | OK | 8.6 | 35.9 | OK | 100 | 13.6 | 0.3 |  |  | OK | Discharging | Charging | Not Docked | Not Docked
2025-08-10 18:10 | 2 |  |  |  |  |  |  |  |  |  |  |  |  |  |  |  | 96 | OK | 28.5 | 44.1 | OK | 41524 | OK |  | OK | 93 | OK
2025-08-10 18:12 | 1 | 96 | OK | 8.6 | 36.4 | OK | 100 | 13.6 | 0.3 |  |  | OK | Discharging | Charging | Not Docked | Not Docked
2025-08-10 18:12 | 2 |  |  |  |  |  |  |  |  |  |  |  |  |  |  |  | 95 | OK | 28.2 | 41.8 | OK | 40835 | OK |  | OK | 93 | OK
2025-08-10 18:14 | 1 | 94 | OK | 8.7 | 37.2 | OK | 100 | 13.7 | 0.3 |  |  | OK | Discharging | Charging | Not Docked | Not Docked
2025-08-10 18:14 | 2 |  |  |  |  |  |  |  |  |  |  |  |  |  |  |  | 95 | OK | 27.7 | 43 | OK | 40360 | OK | 0.6 | OK | 91 | OK
2025-08-10 18:16
2025-08-10 18:16 | 2 |  |  |  |  |  |  |  |  |  |  |  |  |  |  |  | 93 | OK | 27.7 | 45.5 | OK | 39866 | OK |  | OK | 92 | OK
2025-08-10 18:18 | 1 | 96 | OK | 8.8 | 39.7 | OK | 100 | 13.7 | 0.3 |  |  | OK | Discharging | Charging | Not Docked | Not Docked
2025-08-10 18:18 | 2 |  |  |  |  |  |  |  |  |  |  |  |  |  |  |  | 95 | OK | 27.8 | 43.3 | OK | 39257 | OK | 0.5 | OK | 93 | OK
2025-08-10 18:20 | 1 | 95 | OK | 8.9 | 41.4 | OK | 100 | 13.6 | 0.3 |  |  | OK | Discharging | Charging | Not Docked | Not Docked
2025-08-10 18:20 | 2 |  |  |  |  |  |  |  |  |  |  |  |  |  |  |  | 96 | OK | 28 | 43.2 | OK | 38535 | OK | 0.8 | OK | 92 | OK
2025-08-10 18:22 | 1 | 95 | OK | 9 | 43.1 | OK | 100 | 13.6 | 0.3 |  |  | OK | Discharging | Charging | Not Docked | Not Docked
2025-08-10 18:22 | 2 |  |  |  |  |  |  |  |  |  |  |  |  |  |  |  | 95 | OK | 27.4 | 45.7 | OK | 37660 | OK | 0.1 | OK | 93 | OK
2025-08-10 18:24 | 1 | 95 | OK | 9.1 | 44.7 | OK | 100 | 13.6 | 0.3 |  |  | OK | Discharging | Charging | Not Docked | Not Docked
2025-08-10 18:24 | 2 |  |  |  |  |  |  |  |  |  |  |  |  |  |  |  | 92 | OK | 27.8 | 46.7 | OK | 37212 | OK |  | OK | 92 | OK
2025-08-10 18:26 | 1 | 95 | OK | 9.2 | 46.4 | OK | 100 | 13.6 | 0.3 |  |  | OK | Discharging | Charging | Not Docked | Not Docked
2025-08-10 18:26 | 2 |  |  |  |  |  |  |  |  |  |  |  |  |  |  |  | 95 | OK | 27.7 | 43 | OK | 36634 | OK | 1.2 | OK | 93 | OK
2025-08-10 18:28 | 1 | 95 | OK | 9.3 | 47.9 | OK | 100 | 13.6 | 0.3 |  |  | OK | Discharging | Charging | Not Docked | Not Docked
2025-08-10 18:28 | 2 |  |  |  |  |  |  |  |  |  |  |  |  |  |  |  | 96 | OK | 27.5 | 49.5 | OK | 35907 | OK | 0.5 | OK | 93 | OK
2025-08-10 18:30 | 1 | 95 | OK | 9.4 | 49.5 | OK | 100 | 13.6 | 0.3 |  |  | OK | Discharging | Charging | Not Docked | Not Docked
2025-08-10 18:30 | 2 |  |  |  |  |  |  |  |  |  |  |  |  |  |  |  | 95 | OK | 27.8 | 47.8 | OK | 35360 | OK | 0.6 | OK | 93 | OK
2025-08-10 18:32 | 1 | 94 | OK | 9.5 | 50.7 | OK | 100 | 13.6 | 0.3 |  |  | OK | Discharging | Charging | Not Docked | Not Docked
2025-08-10 18:32 | 2 |  |  |  |  |  |  |  |  |  |  |  |  |  |  |  | 95 | OK | 27.1 | 45.1 | OK | 34758 | OK | 0.1 | OK | 93 | OK
2025-08-10 18:34 | 1 | 93 | OK | 9.6 | 51.7 | OK | 100 | 13.7 | 0.3 |  |  | OK | Discharging | Charging | Not Docked | Not Docked
2025-08-10 18:34 | 2 |  |  |  |  |  |  |  |  |  |  |  |  |  |  |  | 95 | OK | 27 | 44.1 | OK | 34350 | OK | 0.5 | OK | 93 | OK
2025-08-10 18:36 | 1 | 95 | OK | 9.7 | 52.6 | OK | 100 | 13.7 | 0.3 |  |  | OK | Discharging | Charging | Not Docked | Not Docked
2025-08-10 18:36 | 2 |  |  |  |  |  |  |  |  |  |  |  |  |  |  |  | 94 | OK | 27.2 | 45.9 | OK | 33737 | OK |  | OK | 91 | OK
2025-08-10 18:38 | 1 | 93 | OK | 9.8 | 53.6 | OK | 100 | 13.7 | 0.3 |  |  | OK | Discharging | Charging | Not Docked | Not Docked
2025-08-10 18:38 | 2 |  |  |  |  |  |  |  |  |  |  |  |  |  |  |  | 93 | OK | 27.5 | 46.7 | OK | 33217 | OK |  | OK | 93 | OK
2025-08-10 18:40 | 1 | 95 | OK | 9.9 | 54.4 | OK | 100 | 13.7 | 0.3 |  |  | OK | Discharging | Charging | Not Docked | Not Docked
2025-08-10 18:40 | 2 |  |  |  |  |  |  |  |  |  |  |  |  |  |  |  | 92 | OK | 27.3 | 46.4 | OK | 32485 | OK |  | OK | 93 | OK
2025-08-10 18:42 | 1 | 95 | OK | 10 | 55.3 | OK | 100 | 13.7 | 0.3 |  |  | OK | Discharging | Charging | Not Docked | Not Docked
2025-08-10 18:42 | 2 |  |  |  |  |  |  |  |  |  |  |  |  |  |  |  | 94 | OK | 27.4 | 48.9 | OK | 26472 | OK |  | OK | 93 | OK
2025-08-10 18:44 | 1 | 95 | OK | 10.1 | 56.2 | OK | 100 | 13.6 | 0.3 |  |  | OK | Discharging | Charging | Not Docked | Not Docked
2025-08-10 18:44 | 2 |  |  |  |  |  |  |  |  |  |  |  |  |  |  |  | 94 | OK | 27.4 | 47.4 | OK | 13235 | OK | 1.2 | OK | 93 | OK
2025-08-10 18:46 | 1 | 95 | OK | 10.1 | 57.1 | OK | 100 | 13.6 | 0.3 |  |  | OK | Discharging | Charging | Not Docked | Not Docked
2025-08-10 18:46 | 2 |  |  |  |  |  |  |  |  |  |  |  |  |  |  |  | 95 | OK | 27 | 48.5 | OK | 9501 | OK |  | OK | 92 | OK
2025-08-10 18:48 | 1 | 95 | OK | 10.2 | 58 | OK | 100 | 13.6 | 0.3 |  |  | OK | Discharging | Charging | Not Docked | Not Docked
2025-08-10 18:48 | 2 |  |  |  |  |  |  |  |  |  |  |  |  |  |  |  | 95 | OK | 26.4 | 49.3 | OK | 8473 | OK |  | OK | 93 | OK
2025-08-10 18:50 | 1 | 96 | OK | 10.3 | 59 | OK | 100 | 13.6 | 0.3 |  |  | OK | Discharging | Charging | Not Docked | Not Docked
2025-08-10 18:50
2025-08-10 18:52 | 1 | 95 | OK | 10.4 | 59.7 | OK | 100 | 13.7 | 0.3 |  |  | OK | Discharging | Charging | Not Docked | Not Docked
2025-08-10 18:52 | 2 |  |  |  |  |  |  |  |  |  |  |  |  |  |  |  | 94 | OK | 26 | 49.2 | OK | 10225 | OK | 0.9 | OK | 92 | OK
2025-08-10 18:54 | 1 | 95 | OK | 10.5 | 60.5 | OK | 100 | 13.6 | 0.3 |  |  | OK | Discharging | Charging | Not Docked | Not Docked
2025-08-10 18:54 | 2 |  |  |  |  |  |  |  |  |  |  |  |  |  |  |  | 93 | OK | 25.7 | 50.2 | OK | 10798 | OK | 0.5 | OK | 92 | OK
2025-08-10 18:56 | 1 | 95 | OK | 10.6 | 61.1 | OK | 100 | 13.6 | 0.3 |  |  | OK | Discharging | Charging | Not Docked | Not Docked
2025-08-10 18:56 | 2 |  |  |  |  |  |  |  |  |  |  |  |  |  |  |  | 91 | OK | 25.7 | 51.1 | OK | 8385 | OK |  | OK | 91 | OK
2025-08-10 18:58 | 1 | 95 | OK | 10.7 | 61.7 | OK | 100 | 13.4 | 0.2 |  |  | OK | Discharging | Charging | Not Docked | Not Docked
2025-08-10 18:58 | 2 |  |  |  |  |  |  |  |  |  |  |  |  |  |  |  | 96 | OK | 25.2 | 50.7 | OK | 7239 | OK |  | OK | 91 | OK
2025-08-10 19:00 | 1 | 93 | OK | 10.6 | 62.4 | OK | 100 | 13.3 | 0.2 |  |  | OK | Discharging | Charging | Not Docked | Not Docked
2025-08-10 19:00 | 2 |  |  |  |  |  |  |  |  |  |  |  |  |  |  |  | 94 | OK | 25.1 | 52.2 | OK | 7093 | OK |  | OK | 92 | OK
2025-08-10 19:02 | 1 | 95 | OK | 10.5 | 63.8 | OK | 100 | 13.3 | 0.2 |  |  | OK | Discharging | Charging | Not Docked | Not Docked
2025-08-10 19:02 | 2 |  |  |  |  |  |  |  |  |  |  |  |  |  |  |  | 95 | OK | 25.1 | 51 | OK | 7014 | OK | 0.4 | OK | 93 | OK
2025-08-10 19:04 | 1 | 95 | OK | 10.4 | 63.4 | OK | 100 | 13.3 | 0.2 |  |  | OK | Discharging | Charging | Not Docked | Not Docked
2025-08-10 19:04 | 2 |  |  |  |  |  |  |  |  |  |  |  |  |  |  |  | 92 | OK | 24.8 | 53.2 | OK | 7163 | OK | 1.2 | OK | 92 | OK
2025-08-10 19:06 | 1 | 95 | OK | 10.3 | 61.1 | OK | 100 | 13.3 | 0.2 |  |  | OK | Discharging | Charging | Not Docked | Not Docked
2025-08-10 19:06 | 2 |  |  |  |  |  |  |  |  |  |  |  |  |  |  |  | 95 | OK | 24.8 | 50.9 | OK | 8500 | OK | 0.9 | OK | 92 | OK
2025-08-10 19:08 | 1 | 95 | OK | 10.1 | 57.6 | OK | 100 | 13.3 | 0.2 |  |  | OK | Discharging | Charging | Not Docked | Not Docked
2025-08-10 19:08 | 2 |  |  |  |  |  |  |  |  |  |  |  |  |  |  |  | 92 | OK | 24.9 | 53.2 | OK | 11045 | OK |  | OK | 92 | OK
2025-08-10 19:10 | 1 | 95 | OK | 10 | 53.5 | OK | 100 | 13.3 | 0.2 |  |  | OK | Discharging | Charging | Not Docked | Not Docked
2025-08-10 19:10 | 2 |  |  |  |  |  |  |  |  |  |  |  |  |  |  |  | 95 | OK | 25.1 | 52.8 | OK | 11844 | OK | 0.7 | OK | 93 | OK
2025-08-10 19:12 | 1 | 95 | OK | 9.8 | 49.8 | OK | 100 | 13.3 | 0.2 |  |  | OK | Discharging | Charging | Not Docked | Not Docked
2025-08-10 19:12 | 2 |  |  |  |  |  |  |  |  |  |  |  |  |  |  |  | 94 | OK | 25.1 | 52.9 | OK | 12384 | OK |  | OK | 93 | OK
2025-08-10 19:14 | 1 | 95 | OK | 9.6 | 47.2 | OK | 100 | 13.3 | 0.1 |  |  | OK | Discharging | Charging | Not Docked | Not Docked
2025-08-10 19:14 | 2 |  |  |  |  |  |  |  |  |  |  |  |  |  |  |  | 94 | OK | 25.3 | 54.3 | OK | 19538 | OK |  | OK | 93 | OK
2025-08-10 19:16 | 1 | 95 | OK | 9.4 | 44.9 | OK | 100 | 13.3 | 0.1 |  |  | OK | Discharging | Charging | Not Docked | Not Docked
2025-08-10 19:16 | 2 |  |  |  |  |  |  |  |  |  |  |  |  |  |  |  | 95 | OK | 25.5 | 52.8 | OK | 16075 | OK |  | OK | 92 | OK
2025-08-10 19:18 | 1 | 95 | OK | 9.2 | 43.1 | OK | 100 | 13.3 | 0.1 |  |  | OK | Discharging | Charging | Not Docked | Not Docked
2025-08-10 19:18 | 2 |  |  |  |  |  |  |  |  |  |  |  |  |  |  |  | 97 | OK | 25.5 | 50.8 | OK | 18085 | OK |  | OK | 92 | OK
2025-08-10 19:20 | 1 | 94 | OK | 9.1 | 41.2 | OK | 100 | 13.3 | 0.1 |  |  | OK | Discharging | Charging | Not Docked | Not Docked
2025-08-10 19:20 | 2 |  |  |  |  |  |  |  |  |  |  |  |  |  |  |  | 98 | OK | 25.3 | 50 | OK | 18045 | OK | 0.8 | OK | 92 | OK
2025-08-10 19:22 | 1 | 95 | OK | 8.9 | 39.5 | OK | 100 | 13.3 | 0.1 |  |  | OK | Discharging | Charging | Not Docked | Not Docked
2025-08-10 19:22 | 2 |  |  |  |  |  |  |  |  |  |  |  |  |  |  |  | 98 | OK | 25.5 | 50.2 | OK | 17323 | OK |  | OK | 92 | OK
2025-08-10 19:24 | 1 | 95 | OK | 8.8 | 38.1 | OK | 100 | 13.2 | 0.1 |  |  | OK | Discharging | Charging | Not Docked | Not Docked
2025-08-10 19:24 | 2 |  |  |  |  |  |  |  |  |  |  |  |  |  |  |  | 97 | OK | 25.8 | 51.8 | OK | 16717 | OK |  | OK | 91 | OK
2025-08-10 19:26 | 1 | 94 | OK | 8.6 | 36.8 | OK | 100 | 13.2 | 0.1 |  |  | OK | Discharging | Charging | Not Docked | Not Docked
2025-08-10 19:26 | 2 |  |  |  |  |  |  |  |  |  |  |  |  |  |  |  | 94 | OK | 25.4 | 49.6 | OK | 16009 | OK | 2.1 | OK | 90 | OK
2025-08-10 19:28 | 1 | 93 | OK | 8.4 | 35.7 | OK | 100 | 13.2 | 0.1 |  |  | OK | Discharging | Charging | Not Docked | Not Docked
2025-08-10 19:28 | 2 |  |  |  |  |  |  |  |  |  |  |  |  |  |  |  | 96 | OK | 25.2 | 52.3 | OK | 15258 | OK | 0.4 | OK | 92 | OK
2025-08-10 19:30 | 1 | 95 | OK | 8.3 | 34.6 | OK | 100 | 13.2 | 0.1 |  |  | OK | Discharging | Charging | Not Docked | Not Docked
2025-08-10 19:30 | 2 |  |  |  |  |  |  |  |  |  |  |  |  |  |  |  | 97 | OK | 25.4 | 51.3 | OK | 14502 | OK |  | OK | 93 | OK
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

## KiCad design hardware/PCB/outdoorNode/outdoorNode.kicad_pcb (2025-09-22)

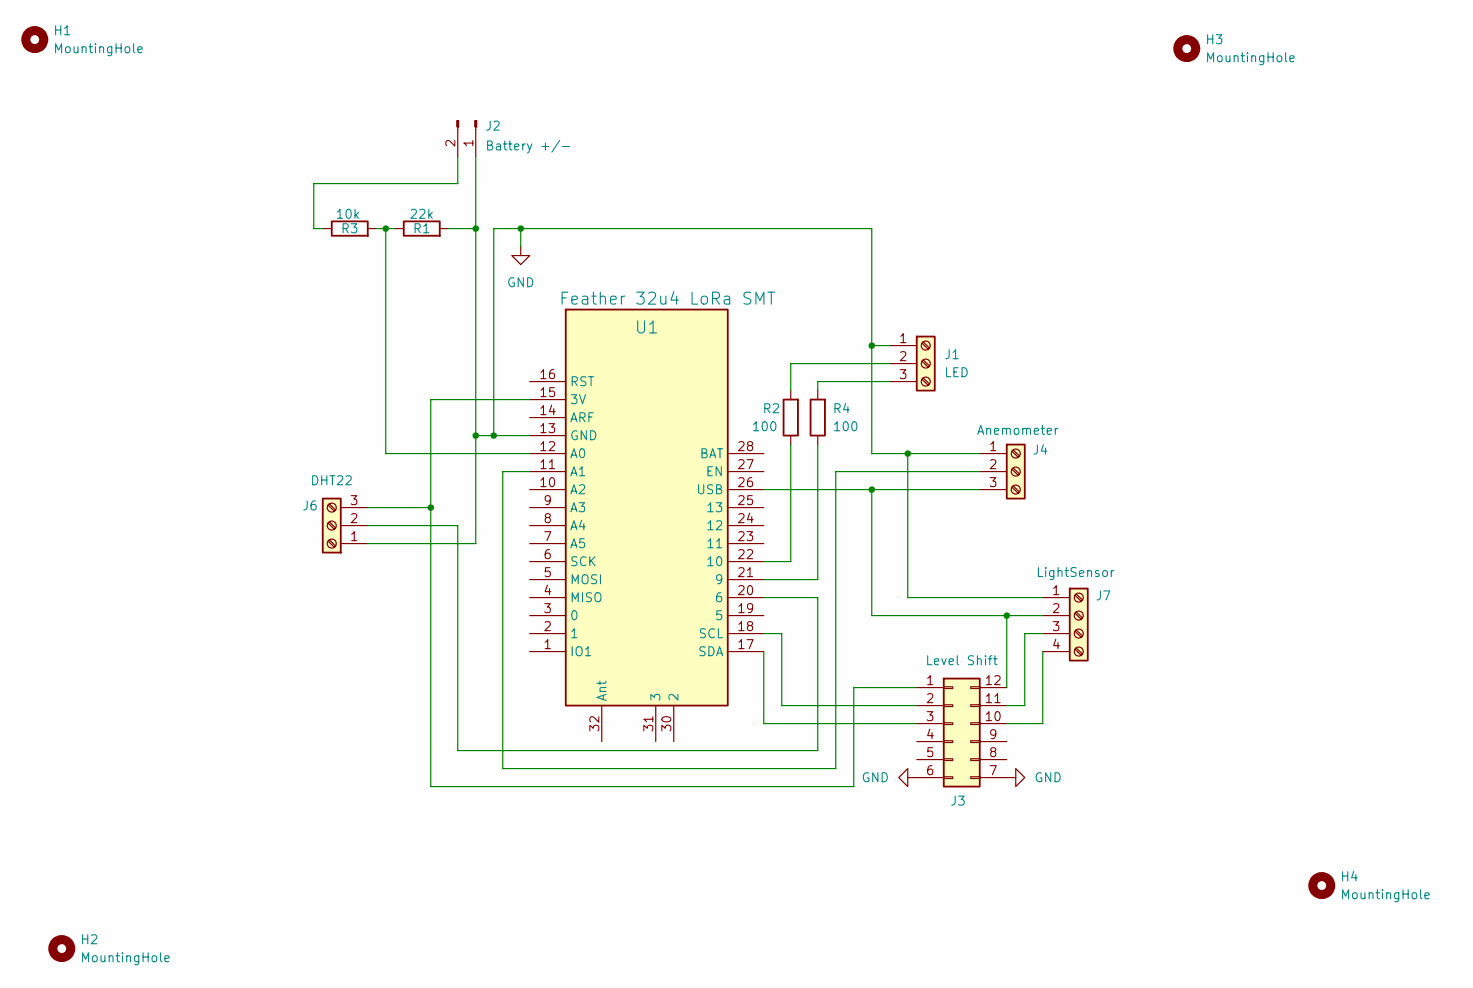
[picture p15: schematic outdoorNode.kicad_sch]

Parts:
H1, H2, H3, H4: MountingHole; MountingHole_4.3mm_M4
J1: LED; TerminalBlock_MaiXu_MX126-5.0-03P_1x03_P5.00mm
J2: Battery +/-; JST_PH_B2B-PH-K_1x02_P2.00mm_Vertical
J3: Level Shift; PinHeader_2x06_P2.54mm_Vertical
J4: Anemometer; TerminalBlock_MaiXu_MX126-5.0-03P_1x03_P5.00mm
J6: DHT22; TerminalBlock_MaiXu_MX126-5.0-03P_1x03_P5.00mm
J7: LightSensor; TerminalBlock_MaiXu_MX126-5.0-04P_1x04_P5.00mm
R1: 22k; R_Axial_DIN0207_L6.3mm_D2.5mm_P10.16mm_Horizontal
R2, R4: 100; R_Axial_DIN0207_L6.3mm_D2.5mm_P10.16mm_Horizontal
R3: 10k; R_Axial_DIN0207_L6.3mm_D2.5mm_P10.16mm_Horizontal
U1: Feather 32u4 LoRa SMT; mod2_Adafruit_Feather_32u4_RFM_WithMountingHoles_1

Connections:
GND: J1.1, J2.1, J3.6 (GND), J3.7 (GND), J4.1, J6.1, J7.1, R1.2, U1.13 (GND)
unnamed: J1.2, R2.2
unnamed: J1.3, R4.2
unnamed: J2.2, R3.1
unnamed: J3.2 (A1), U1.18 (SCL)
unnamed: J3.3 (A2), U1.17 (SDA)
unnamed: J3.11 (B1), J7.3
unnamed: J3.10 (B2), J7.4
unnamed: J3.12 (HV), J4.3, J7.2, U1.26 (USB)
unnamed: J3.1 (LV), J6.3, U1.15 (3V)
unnamed: J4.2, U1.11 (A1)
unnamed: J6.2, U1.20 (6)
unnamed: R4.1, U1.21 (9)
unnamed: R2.1, U1.22 (10)
unnamed: R1.1, R3.2, U1.12 (A0)

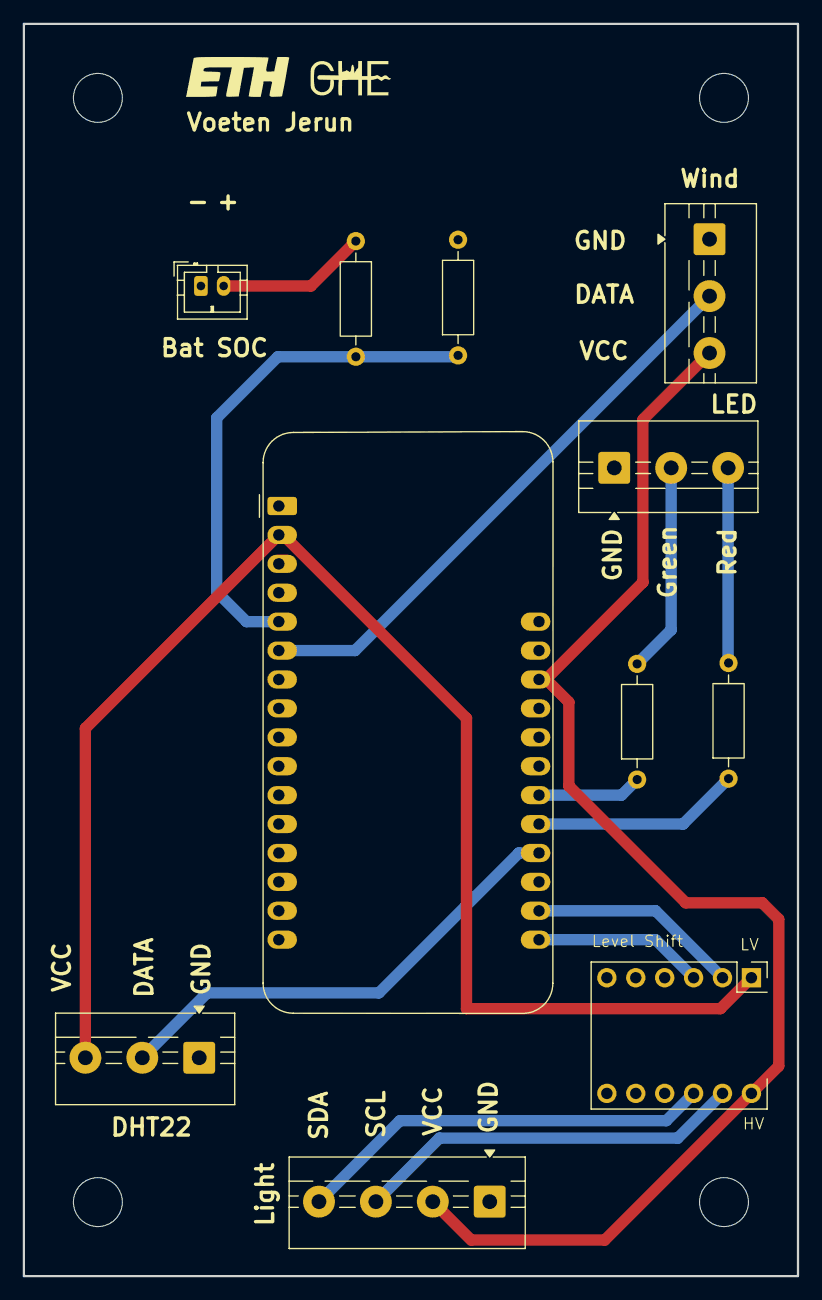
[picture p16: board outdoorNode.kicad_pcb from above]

Board: 2 copper layers, 68.0 x 110.0 mm, 15 parts (0 on the bottom side), 15 nets.

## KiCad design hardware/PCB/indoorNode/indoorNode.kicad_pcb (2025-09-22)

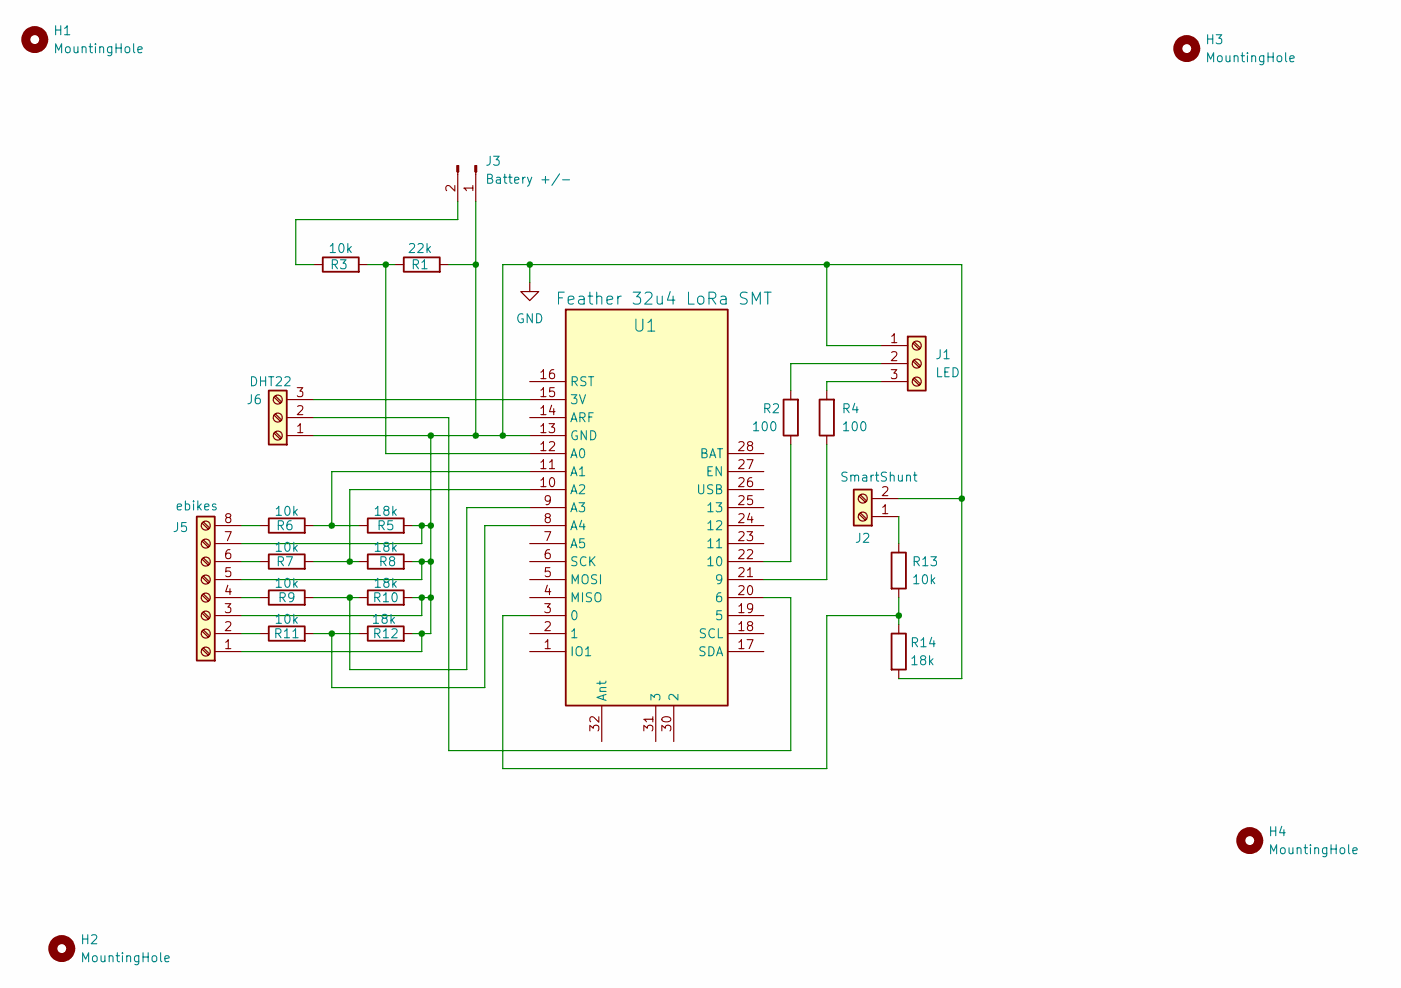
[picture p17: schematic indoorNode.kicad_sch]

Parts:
H1, H2, H3, H4: MountingHole; MountingHole_4.3mm_M4
J1: LED; TerminalBlock_MaiXu_MX126-5.0-03P_1x03_P5.00mm
J2: SmartShunt; TerminalBlock_MaiXu_MX126-5.0-02P_1x02_P5.00mm
J3: Battery +/-; JST_PH_B2B-PH-K_1x02_P2.00mm_Vertical
J5: ebikes; TerminalBlock_MaiXu_MX126-5.0-08P_1x08_P5.00mm
J6: DHT22; TerminalBlock_MaiXu_MX126-5.0-03P_1x03_P5.00mm
R1: 22k; R_Axial_DIN0207_L6.3mm_D2.5mm_P10.16mm_Horizontal
R2, R4: 100; R_Axial_DIN0207_L6.3mm_D2.5mm_P10.16mm_Horizontal
R3, R6, R7, R9, R11, R13: 10k; R_Axial_DIN0207_L6.3mm_D2.5mm_P10.16mm_Horizontal
R5, R8, R10, R12, R14: 18k; R_Axial_DIN0207_L6.3mm_D2.5mm_P10.16mm_Horizontal
U1: Feather 32u4 LoRa SMT; mod2_Adafruit_Feather_32u4_RFM_WithMountingHoles_1

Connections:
GND: J1.1, J2.2, J3.1, J5.1, J5.3, J5.5, J5.7, J6.1, R1.2, R5.2, R8.2, R10.2, R12.2, R14.2, U1.13 (GND)
unnamed: J1.2, R2.2
unnamed: J1.3, R4.2
unnamed: J2.1, R13.1
unnamed: J3.2, R3.1
unnamed: J5.2, R11.1
unnamed: J5.4, R9.1
unnamed: J5.6, R7.1
unnamed: J5.8, R6.1
unnamed: J6.2, U1.20 (6)
unnamed: J6.3, U1.15 (3V)
unnamed: R13.2, R14.1, U1.3 (0)
unnamed: R4.1, U1.21 (9)
unnamed: R2.1, U1.22 (10)
unnamed: R1.1, R3.2, U1.12 (A0)
unnamed: R5.1, R6.2, U1.11 (A1)
unnamed: R7.2, R8.1, U1.10 (A2)
unnamed: R9.2, R10.1, U1.9 (A3)
unnamed: R11.2, R12.1, U1.8 (A4)

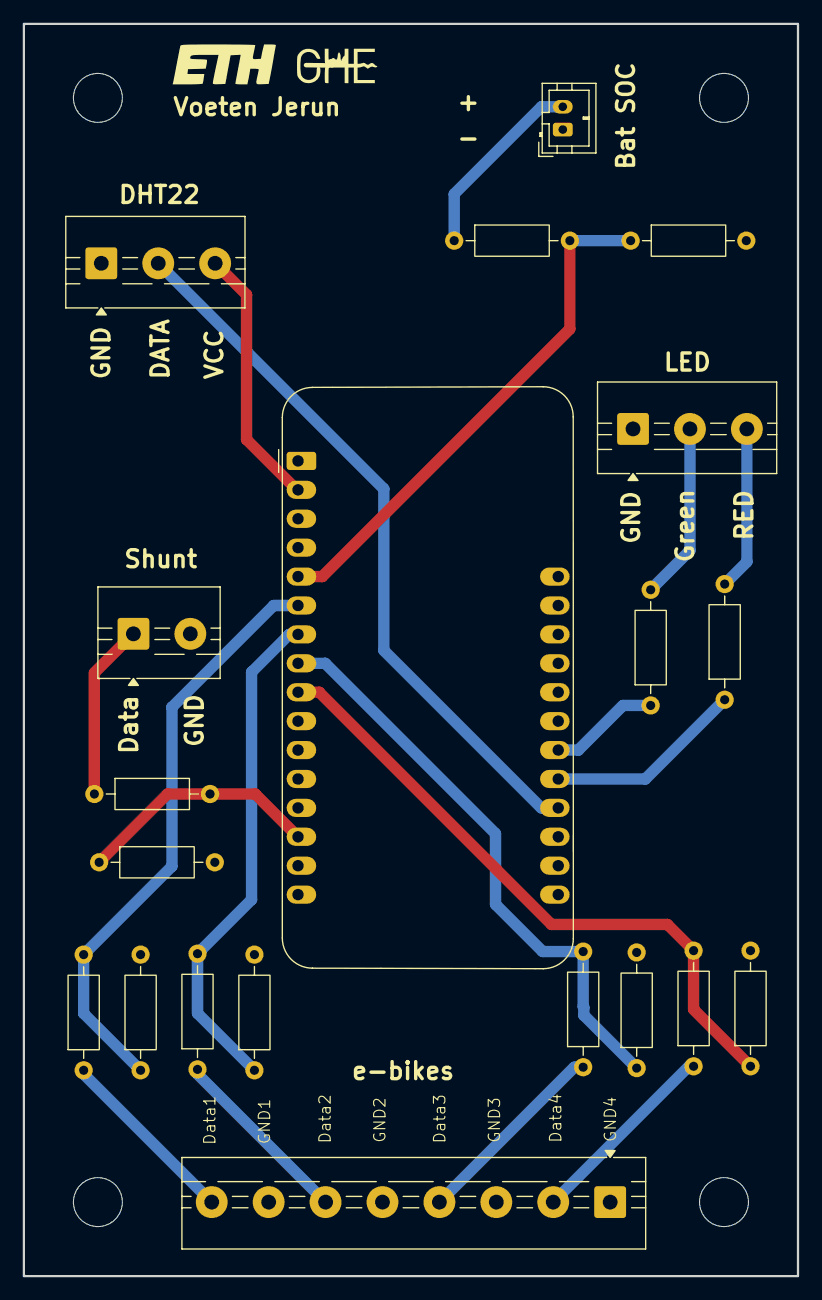
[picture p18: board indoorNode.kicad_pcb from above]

Board: 2 copper layers, 68.0 x 110.0 mm, 24 parts (0 on the bottom side), 19 nets.

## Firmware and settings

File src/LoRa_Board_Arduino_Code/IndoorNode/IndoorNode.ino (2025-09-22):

// ETH Zürich
// Global Health Engineering Lab
// Masterthesis Voeten Jerun
// Indoor Node Skript
// August 2025

#include <SPI.h>
#include <LoRa.h>
#include <DHT.h>
#include <Wire.h>
#include <avr/wdt.h>
#include <math.h>

// Define sensor pin assignments
#define DHTPIN       6       // Pin for DHT22 data line
#define DHTTYPE      DHT22   // Specify DHT sensor type
#define PB_PIN       A0      // Analog pin for battery voltage measurement

const int LEDPinRed   = 9;
const int LEDPinGreen = 10;

// Disable watchdog early during startup (before C runtime begins)
void disableWatchdog() __attribute__((naked)) __attribute__((section(".init3")));
void disableWatchdog() {
  MCUSR = 0;          // Clear MCU status register to reset flags
  wdt_disable();      // Disable the watchdog timer
}

// DHT sensor object for temperature and humidity readings
DHT dht(DHTPIN, DHTTYPE);

// Node configuration and timing for transmission
const uint8_t node = 1;  // Node ID for this device: indoor node
const unsigned long interval = 120000;
unsigned long previousMillis = 0;

// Default values for sensor fallbacks
const int16_t DEF_TEMP   = 250;   // Default encoded temperature (25.0°C)
const uint16_t DEF_HUM   = 500;   // Default encoded humidity (50.0%)
const float DEF_CUR1   = 0;  // Default current ebike 1
const float DEF_CUR2  = 0;     // Default current ebike 2
const uint8_t DEF_BATSOC = 100;   // Default battery state of charge (%)

// Store last successful sensor readings
int16_t lastTemp;   
int16_t lastHum;     
float lastCur1;
float lastCur2;
uint8_t lastBatSOC;

// Define sensor boundaries
int16_t maxDeltaTemp = 200, maxDeltaHum = 400, minTemp = -400, maxTemp = 800, minHum = 0, maxHum = 1000; //values/10 = °C,%
int16_t maxDeltaBat = 40, lowBat = 25, criticalBat = 15; // %

// Retry configuration for various sensors
int DHT_MAX_TRIES  = 4;
int DHT_NEED_GOOD  = 2;
int CUR_MAX_TRIES = 6;
int CUR_NEED_GOOD = 4;
int SOC_MAX_TRIES  = 5;
int SOC_NEED_GOOD  = 3;

// current sensor specs & calib
const float mVperAmp   = 100.0f;      // 20A current sensor sensitivity
const double ACSoffset1 = 2569.0;     // Sensor1 no-load offset in mV
const double ACSoffset2 = 2505.0;     // Sensor2 no-load offset in mV

// Bitmask to indicate which sensors failed (1 = failure)
uint8_t sensorState = 0b0000; // 1st bit (MSB): dht, 2nd bit: smart shunt, 4th bit (LSB): bat soc

// Buffers and flags for SmartShunt telemetry data
float mainBatSOC      = 0.0f;
float mainBatVoltage  = 0.0f;
float mainBatCurrent  = 0.0f;
int32_t mainBatCE     = 0; // consumed Amp Hours 
uint16_t mainBatChargeCycles = 0; // H4
bool hasCE  = false, hasH4 = false;
bool hasSOC = false, hasV  = false, hasI  = false;
char lineBuf[64];   // Buffer for incoming SmartShunt data lines
uint8_t bufIdx = 0;  // Write index for buffer

//----------------------------------------------------------------------------
// CRC-8 calculation (Dallas/Maxim algorithm)
uint8_t crc8(const uint8_t *data, size_t len) {
  uint8_t crc = 0x00;
  while (len--) {
    uint8_t extract = *data++;
    for (uint8_t tempI = 8; tempI; tempI--) {
      uint8_t sum = (crc ^ extract) & 0x01;
      crc >>= 1;
      if (sum) crc ^= 0x8C;
      extract >>= 1;
    }
  }
  return crc;
}

//----------------------------------------------------------------------------
// Secure DHT22 reading: averages multiple samples, enforces bounds
bool readDHT22(int16_t &fridgeTemp, int16_t &fridgeHum, bool init = false) {
  int tries = 0, good = 0;
  int32_t sumT = 0, sumH = 0;

  // Attempt multiple readings until enough good ones are obtained
  while (tries < DHT_MAX_TRIES && good < DHT_NEED_GOOD) {
    tries++;
    float t = dht.readTemperature();    // Raw temperature
    float h = dht.readHumidity();       // Raw humidity
    bool ok = false;

    if (!isnan(t) && !isnan(h)) {
      int16_t t_int = (int16_t)roundf(t * 10.0f);
      int16_t h_int = (int16_t)roundf(h * 10.0f);

      // Validate reading ranges
      if (t_int >= minTemp && t_int <= maxTemp && h_int <= maxHum) {
        // Accept if within allowed delta or during initialization
        if (init || (abs(t_int - lastTemp) <= maxDeltaTemp && abs(h_int - lastHum) <= maxDeltaHum)) {
          ok = true;
          sumT += t_int;
          sumH += h_int;
        }
      }
    }

    if (ok) good++;
    wdt_reset();  // Reset watchdog to prevent reset
   
    // Delay between tries, skip if initialization only needs one
    if (!ok || init) delay(2000);
  }

  bool valid = (good >= DHT_NEED_GOOD);
  int16_t avgT = valid ? sumT / DHT_NEED_GOOD : DEF_TEMP;
  int16_t avgH = valid ? sumH / DHT_NEED_GOOD : DEF_HUM;

  if (valid) {
    fridgeTemp = avgT;
    fridgeHum  = avgH;
    lastTemp = avgT;
    lastHum  = avgH;
    sensorState &= ~0b1000;   // Clear DHT error flag
  } else {
    if (init) {
      lastTemp = DEF_TEMP;
      lastHum = DEF_HUM;
      fridgeTemp = DEF_TEMP;
      fridgeHum = DEF_HUM;
    }
    sensorState |= 0b1000;    // Set DHT error flag
  }
  
  return valid;
}

//----------------------------------------------------------------------------
// Read current in amps from analog pin, apply calibration and averaging
bool readCurrent(int analogPin, float &currentA, bool init = false) {

  int tries = 0, good = 0;
  float sumC = 0.0f;

  while (tries < CUR_MAX_TRIES && good < CUR_NEED_GOOD) {
    tries++;
    int raw = analogRead(analogPin);  // Raw ADC value
    
    // Convert ADC to voltage in mV
    float rawVoltage_mV = raw * (3300.0f / 1023.0f);
    // Voltage divider correction
    float voltage_mV = rawVoltage_mV * ((18.0f + 10.0f) / 18.0f); // 18kohm & 10kohm resistors
    // Calculate current: subtract offset, divide by sensitivity
    float c = (voltage_mV - (analogPin == A1 ? ACSoffset1 : ACSoffset2)) / mVperAmp;
    
    // Serial.println(voltage_mV); // usefull for calibration -> ACSoffset
    
    sumC += c;
    good++;
    delay(200);
  }

  bool valid = (good >= CUR_NEED_GOOD);
  float avgC = valid ? sumC / CUR_NEED_GOOD : (analogPin == A1 ? lastCur1 : lastCur2);

  if (valid) {
    currentA = avgC;
    if (analogPin == A1) lastCur1 = avgC;
    else                 lastCur2 = avgC;
  } else {
      if (init) {
        if (analogPin == A1) lastCur1 = DEF_CUR1, currentA = DEF_CUR1;
        else                 lastCur2 = DEF_CUR2, currentA = DEF_CUR2;
      }
    //currentA = (analogPin == A1 ? lastCur1 : lastCur2);
  }

  // Serial.print("Strom A");
  // Serial.print(analogPin - A0);
  // Serial.print(" = ");
  // Serial.println(currentA, 3);
  return valid;
}

//----------------------------------------------------------------------------
// Read battery SOC from analog pin, convert voltage to percentage, update LEDs
bool readBatterySOC(uint8_t &soc, bool init = false) {

  int tries = 0, good = 0;
  int sumB = 0;

  while (tries < SOC_MAX_TRIES && good < SOC_NEED_GOOD) {
    tries++;
    int raw = analogRead(PB_PIN);
    float bVolt = raw * (3.3f / 1023.0f) * ((22.0f + 10.0f) / 22.0f);
    int bSOC = map((int)roundf(bVolt * 100.0f), 300, 420, 0, 100);
    uint8_t bSOC_int = (uint8_t)constrain(bSOC, 0, 100);

    bool ok = false;
    if (init || (abs((int)bSOC_int - (int)lastBatSOC) <= maxDeltaBat)) {
      sumB += bSOC_int;
      ok = true;
    }
    if (ok) good++;
    delay(200);
  }

  bool valid = (good >= SOC_NEED_GOOD);
  uint8_t avgB = valid ? sumB / SOC_NEED_GOOD : DEF_BATSOC;

  if (valid) {
    soc = avgB;
    lastBatSOC = avgB;
    sensorState &= ~0b0001;  // Clear SOC error flag
  } else {
    if (init) {
      lastBatSOC = DEF_BATSOC;
      soc = DEF_BATSOC;
    }
    sensorState |= 0b0001;   // Set SOC error flag
  }

  // LED indication: red <15%, green off >25%
  if (soc > lowBat) {
    digitalWrite(LEDPinRed, LOW);
    digitalWrite(LEDPinGreen, LOW);
  } else if (soc < criticalBat) {
    digitalWrite(LEDPinRed, HIGH);
    digitalWrite(LEDPinGreen, LOW);
  } else {
    digitalWrite(LEDPinRed, HIGH);
    digitalWrite(LEDPinGreen, HIGH);
  }

  return valid;
}

//----------------------------------------------------------------------------
// Parse tab-separated SmartShunt data lines into variables
void parseShunt(const String &line) {
  int idx = line.indexOf('\t');
  if (idx < 0) return;
  String key = line.substring(0, idx);
  String val = line.substring(idx + 1);

  if (key == "SOC") {
    mainBatSOC = val.toFloat() / 10.0f;
    hasSOC = true;
  } else if (key == "V") {
    mainBatVoltage = val.toFloat() / 1000.0f;
    hasV = true;
  } else if (key == "I") {
    mainBatCurrent = val.toFloat() / 1000.0f;
    hasI = true;
  } else if (key == "CE") {
    mainBatCE = val.toInt();
    hasCE = true;
  } else if (key == "H4") {
    mainBatChargeCycles = val.toInt();
    hasH4 = true;
  }
}

//----------------------------------------------------------------------------
// Initialize last valid readings for all sensors at startup
void initializeLastValues() {

  lastTemp     = DEF_TEMP;
  lastHum      = DEF_HUM;
  lastCur1      = DEF_CUR1;
  lastCur2   = DEF_CUR2;
  lastBatSOC      = DEF_BATSOC;

  int16_t t;   int16_t h;
  readDHT22(t, h, true);

  // Initialize eBike current sensors
  float c1, c2;
  readCurrent(A1, c1, true);
  readCurrent(A2, c2, true);

  uint8_t b;
  readBatterySOC(b, true);

  // Adjust retry parameters for normal operation
  DHT_MAX_TRIES  = 2;
  DHT_NEED_GOOD  = 1;
  CUR_MAX_TRIES = 5;
  CUR_NEED_GOOD = 3;
  SOC_MAX_TRIES  = 4;
  SOC_NEED_GOOD  = 2;
}

//----------------------------------------------------------------------------
void setup() {
  Serial.begin(9600);
  delay(3000);

  Wire.begin();

  Serial1.begin(19200); // smart shunt communication

  randomSeed(analogRead(A5));  // Seed random for jitter, A5: random signal

  pinMode(LEDPinRed,   OUTPUT);
  pinMode(LEDPinGreen, OUTPUT);

  // Initialize LoRa module for 868 MHz
  LoRa.setPins(8, 4, 7);
  if (!LoRa.begin(868E6)) {
    while (1);
  }

  // Start DHT sensor
  dht.begin();

  initializeLastValues();

  digitalWrite(LEDPinRed, LOW);
  digitalWrite(LEDPinGreen, LOW);
  // Enable watchdog with 8s timeout
  wdt_enable(WDTO_8S);
}

//----------------------------------------------------------------------------
void loop() {
  wdt_reset();
  // Read and parse incoming SmartShunt data on Serial1
  while (Serial1.available()) {
    char c = Serial1.read();
    if (c == '\n' || c == '\r') {
      if (bufIdx > 0) {
        lineBuf[bufIdx] = '\0';
        parseShunt(String(lineBuf));
        bufIdx = 0;
        sensorState &= ~0b0100;
      }
    } else {
      if (bufIdx < sizeof(lineBuf) - 1) {
        lineBuf[bufIdx++] = c;
      } else {
        bufIdx = 0;
        sensorState |= 0b0100;
      }
    }
  }

  wdt_reset();  // Reset watchdog periodically

  unsigned long now = millis();  // Current time in ms

  // Check if it's time to read sensors and send data
  if (now - previousMillis >= interval) {
    
    delay(random(0, 5000));         // Add jitter to avoid collisions
    previousMillis = now;
    wdt_reset();    

    // 1. Read DHT22 sensors
    int16_t inT, inH;
    if (!readDHT22(inT, inH)) {
      inT = lastTemp;
      inH = lastHum;
    }

    wdt_reset();  
    // 2. Read InNode battery SOC
    uint8_t InNodeBatSOC;
    if (!readBatterySOC(InNodeBatSOC)) InNodeBatSOC = lastBatSOC;
    
    wdt_reset();  
    // 3. Read currents from both channels
    float cur1 = 0.0f, cur2 = 0.0f;
    if (!readCurrent(A1, cur1)) cur1 = lastCur1;
    if (!readCurrent(A2, cur2)) cur2 = lastCur2;

    // Determine eBike states: 0=off,1=charging,2=discharging
    uint8_t eBikeState1 = (cur1 >  0.1f ? 1 : (cur1 < -0.1f ? 2 : 0));
    uint8_t eBikeState2 = (cur2 >  0.1f ? 1 : (cur2 < -0.1f ? 2 : 0));
    uint8_t eBikeStatePacked = (eBikeState1 & 0x03) | ((eBikeState2 & 0x03) << 2);

    wdt_reset();  
    
    // prepare payload
    uint8_t signByte = 0;
    if (inT < 0)      signByte |= (1 << 0);
    if (mainBatCurrent < 0.0f) signByte |= (1 << 1);
    if (mainBatCE < 0)         signByte |= (1 << 2);
    uint16_t tempAbs = (uint16_t)abs(inT);
    uint16_t hum = inH;
    uint16_t socMain = (uint16_t)round(mainBatSOC * 10.0f);
    uint16_t volt_enc = (uint16_t)round(mainBatVoltage * 10.0f);
    uint16_t curr_abs = (uint16_t)roundf(fabs(mainBatCurrent) * 10.0f);
    int32_t ceValAbs = abs(mainBatCE); // consumed_mAh

    uint8_t payload[21] = {0};
    // Build LoRa payload byte by byte
    payload[0] = node;  // Node ID
    payload[1] = signByte;
    payload[2] = (tempAbs >> 8) & 0xFF;
    payload[3] =  tempAbs       & 0xFF;
    payload[4] = (hum >> 8) & 0xFF;
    payload[5] =  hum       & 0xFF;
    payload[6] = InNodeBatSOC;
    payload[7] = (socMain >> 8) & 0xFF;
    payload[8] =  socMain       & 0xFF;
    payload[9]  = (volt_enc >> 8) & 0xFF;
    payload[10] =  volt_enc       & 0xFF;
    payload[11] = (curr_abs >> 8) & 0xFF;
    payload[12] =  curr_abs       & 0xFF;    
    payload[13] = (ceValAbs >> 16) & 0xFF;
    payload[14] = (ceValAbs >> 8)  & 0xFF;
    payload[15] =  ceValAbs        & 0xFF;
    payload[16] = (mainBatChargeCycles >> 8) & 0xFF;
    payload[17] =  mainBatChargeCycles       & 0xFF;
    payload[18] = eBikeStatePacked;
    payload[19] = sensorState;
    payload[20] = crc8(payload, 20);

    // Send packet via LoRa
    LoRa.beginPacket();
    LoRa.write(payload, sizeof(payload));
    LoRa.endPacket();

  }
}

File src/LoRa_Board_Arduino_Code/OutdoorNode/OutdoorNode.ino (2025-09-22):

// ETH Zürich
// Global Health Engineering Lab
// Masterthesis Voeten Jerun
// Outdoor Node Skript
// August 2025

#include <SPI.h>
#include <LoRa.h>
#include <DHT.h>
#include <Wire.h>
#include <avr/wdt.h>

// Define sensor pin assignments and constants
#define DHT_PIN       6       // Pin for DHT22 data line
#define DHT_TYPE      DHT22   // Specify DHT sensor type
#define PB_PIN        A0      // Analog pin for battery voltage measurement
#define WIND_PIN      A1      // Pin for wind speed sensor
#define LIGHT_ADDR    0x23    // I2C address for light sensor

const int LEDPinRed   = 9;    // Red LED pin
const int LEDPinGreen = 10;   // Green LED pin

// Disable watchdog early during startup (before C runtime begins)
void disableWatchdog() __attribute__((naked)) __attribute__((section(".init3")));
void disableWatchdog() {
  MCUSR = 0;                // Clear MCU status register
  wdt_disable();            // Disable the watchdog timer
}

// Instantiate the DHT sensor object
DHT dht(DHT_PIN, DHT_TYPE);

// Node configuration and timing for transmission
const uint8_t node       = 2;            // Node ID for this device: outdoor node
const unsigned long interval = 120000;    // Interval between measurements (ms)
unsigned long previousMillis = 0;         // Timestamp of last measurement

// Default values for sensor fallbacks
const int16_t DEF_TEMP   = 250;   // Default encoded temperature (25.0°C)
const uint16_t DEF_HUM   = 500;   // Default encoded humidity (50.0%)
const uint16_t DEF_LUX   = 1000;  // Default illuminance (lux)
const uint16_t DEF_WIND  = 0;     // Default wind speed (m/s)
const uint8_t DEF_BATSOC = 100;   // Default battery state of charge (%)

// Store last successful sensor readings
int16_t lastTemp;
int16_t lastHum;
uint16_t lastLux;
uint16_t lastWindspeed;
uint8_t  lastBatSOC;

// Define sensor boundaries
int16_t maxDeltaTemp = 200, maxDeltaHum = 400, minTemp = -400, maxTemp = 800, minHum = 0, maxHum = 1000; //values/10 = °C,%
uint16_t maxLux = 54612; // lux
int16_t maxDeltaWind = 300, maxWind = 500; // values / 10 = m/s
int16_t maxDeltaBat = 40, lowBat = 25, criticalBat = 15; // %

// Retry configuration for various sensors
int MAX_TRIES = 5;
int NEED_GOOD = 3;
int DHT_MAX_TRIES = 4;
int DHT_NEED_GOOD = 2;

// Bitmask to indicate which sensors failed (1 = failure)
uint8_t sensorState = 0b0000; // 1st bit (MSB): dht, 2nd: light sensor, 3rd: wind sensor, 4th (LSB): bat soc

//----------------------------------------------------------------------------
// Compute CRC-8 checksum for given data buffer
uint8_t crc8(const uint8_t *data, size_t len) {
  uint8_t crc = 0x00;
  while (len--) {
    uint8_t extract = *data++;
    for (uint8_t tempI = 8; tempI; tempI--) {
      uint8_t sum = (crc ^ extract) & 0x01;
      crc >>= 1;
      if (sum) crc ^= 0x8C;
      extract >>= 1;
    }
  }
  return crc;
}

//----------------------------------------------------------------------------
// Read a block of registers from the light sensor over I2C
uint8_t readReg(uint8_t reg, uint8_t *pBuf, size_t size) {
  Wire.beginTransmission((uint8_t)LIGHT_ADDR);
  Wire.write(reg);
  if (Wire.endTransmission() != 0) return 0;  // Transmission failed
  delay(20);                                  // Wait for sensor
  Wire.requestFrom((uint8_t)LIGHT_ADDR, (uint8_t)size);
  for (uint8_t i = 0; i < size; i++) {
    pBuf[i] = Wire.read();                    // Read data bytes
  }
  return size;
}

//----------------------------------------------------------------------------
// Read temperature and humidity from the DHT22 with multiple tries and validation
bool readDHT22(int16_t &tVal, uint16_t &hVal, bool init = false) {
  int tries = 0, good = 0;
  int32_t sumT = 0, sumH = 0;

  // Attempt multiple readings until enough good ones are obtained
  while (tries < DHT_MAX_TRIES && good < DHT_NEED_GOOD) {
    tries++;
    float t = dht.readTemperature();
    float h = dht.readHumidity();

    bool ok = false;
    if (!isnan(t) && !isnan(h)) {
      int16_t t_int = (int16_t)roundf(t * 10.0f);
      int16_t h_int = (int16_t)roundf(h * 10.0f);

      // Validate against expected ranges and last readings
      if (t_int >= minTemp && t_int <= maxTemp && h_int <= maxHum) {
        if (init || (abs(t_int - lastTemp) <= maxDeltaTemp && abs(h_int - lastHum) <= maxDeltaHum)) {
          ok = true;
          sumT += t_int;
          sumH += h_int;
        }
      }
    }

    if (ok) good++;
    wdt_reset();                            // Reset watchdog
    if (!ok || init) delay(2000);          // Delay between attempts
  }

  bool valid = (good >= DHT_NEED_GOOD);
  int16_t avgT = valid ? sumT / DHT_NEED_GOOD : DEF_TEMP;
  uint16_t avgH = valid ? sumH / DHT_NEED_GOOD : DEF_HUM;

  if (valid) {
    tVal = avgT;
    hVal = avgH;
    lastTemp = avgT;
    lastHum = avgH;
    sensorState &= ~0b1000;                // Clear humidity/temperature error flag
  } else {
    if (init) {
      lastTemp = DEF_TEMP;
      lastHum = DEF_HUM;
      tVal = DEF_TEMP;
      hVal = DEF_HUM;
    }
    sensorState |= 0b1000;                 // Set error flag on failure
  }

  return valid;
}

//----------------------------------------------------------------------------
// Read ambient illuminance (lux) with retries and averaging
bool readIlluminance(uint16_t &luxVal, bool init = false) {

  int tries = 0, good = 0;
  int32_t sumL = 0;

  while (tries < MAX_TRIES && good < NEED_GOOD) {
    tries++;
    uint8_t buf[2];
    if (readReg(0x10, buf, 2) == 2) {
      uint16_t raw = (buf[0] << 8) | buf[1];
      uint16_t l = (uint16_t)(raw / 1.2f);

      if (l <= maxLux) {
        sumL += l;
        good++;
      }
    }
    delay(200);
  }

  bool valid = (good >= NEED_GOOD);
  uint16_t avgL = valid ? sumL / NEED_GOOD : DEF_LUX;

  if (valid) {
    luxVal = avgL;
    lastLux = avgL;
    sensorState &= ~0b0100;                // Clear illuminance error flag
  } else {
    if (init) {
      lastLux = DEF_LUX;
      luxVal = DEF_LUX;
    }
    sensorState |= 0b0100;                 // Set error flag
  }

  return valid;
}
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

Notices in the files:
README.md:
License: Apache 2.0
